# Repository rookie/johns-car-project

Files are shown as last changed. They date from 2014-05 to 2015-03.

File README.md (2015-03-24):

Overview
========

The goal of this project it to build a display for a car's instrument panel.

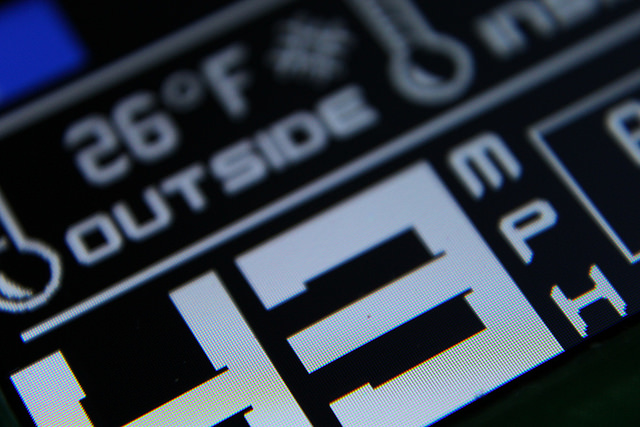
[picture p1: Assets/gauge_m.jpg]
Gauge display


Display will include
- Engine coolant temp
- External temp
- Internal temp
- Speed (from GPS)
- Time (from GPS)
- Date (from GPS)
- Button input to toggle display between Metric to Imperial
- Button input to toggle time offset for Daylight Saving

Parts List
==========

- 1x Arduino Pro Mini 328 - https://www.sparkfun.com/products/11113
- 1x Adafruit 2.2" LCD - http://www.adafruit.com/products/1480
- 1x Adafruit Ultimate GPS - http://www.adafruit.com/products/746
- 3x ACDelco / GM Ambient Temperature Sensor (10K @ 25°C) - http://www.newgmparts.com/oe-gm/15936931

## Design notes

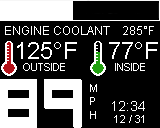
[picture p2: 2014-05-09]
Assets/gauge2.bmp

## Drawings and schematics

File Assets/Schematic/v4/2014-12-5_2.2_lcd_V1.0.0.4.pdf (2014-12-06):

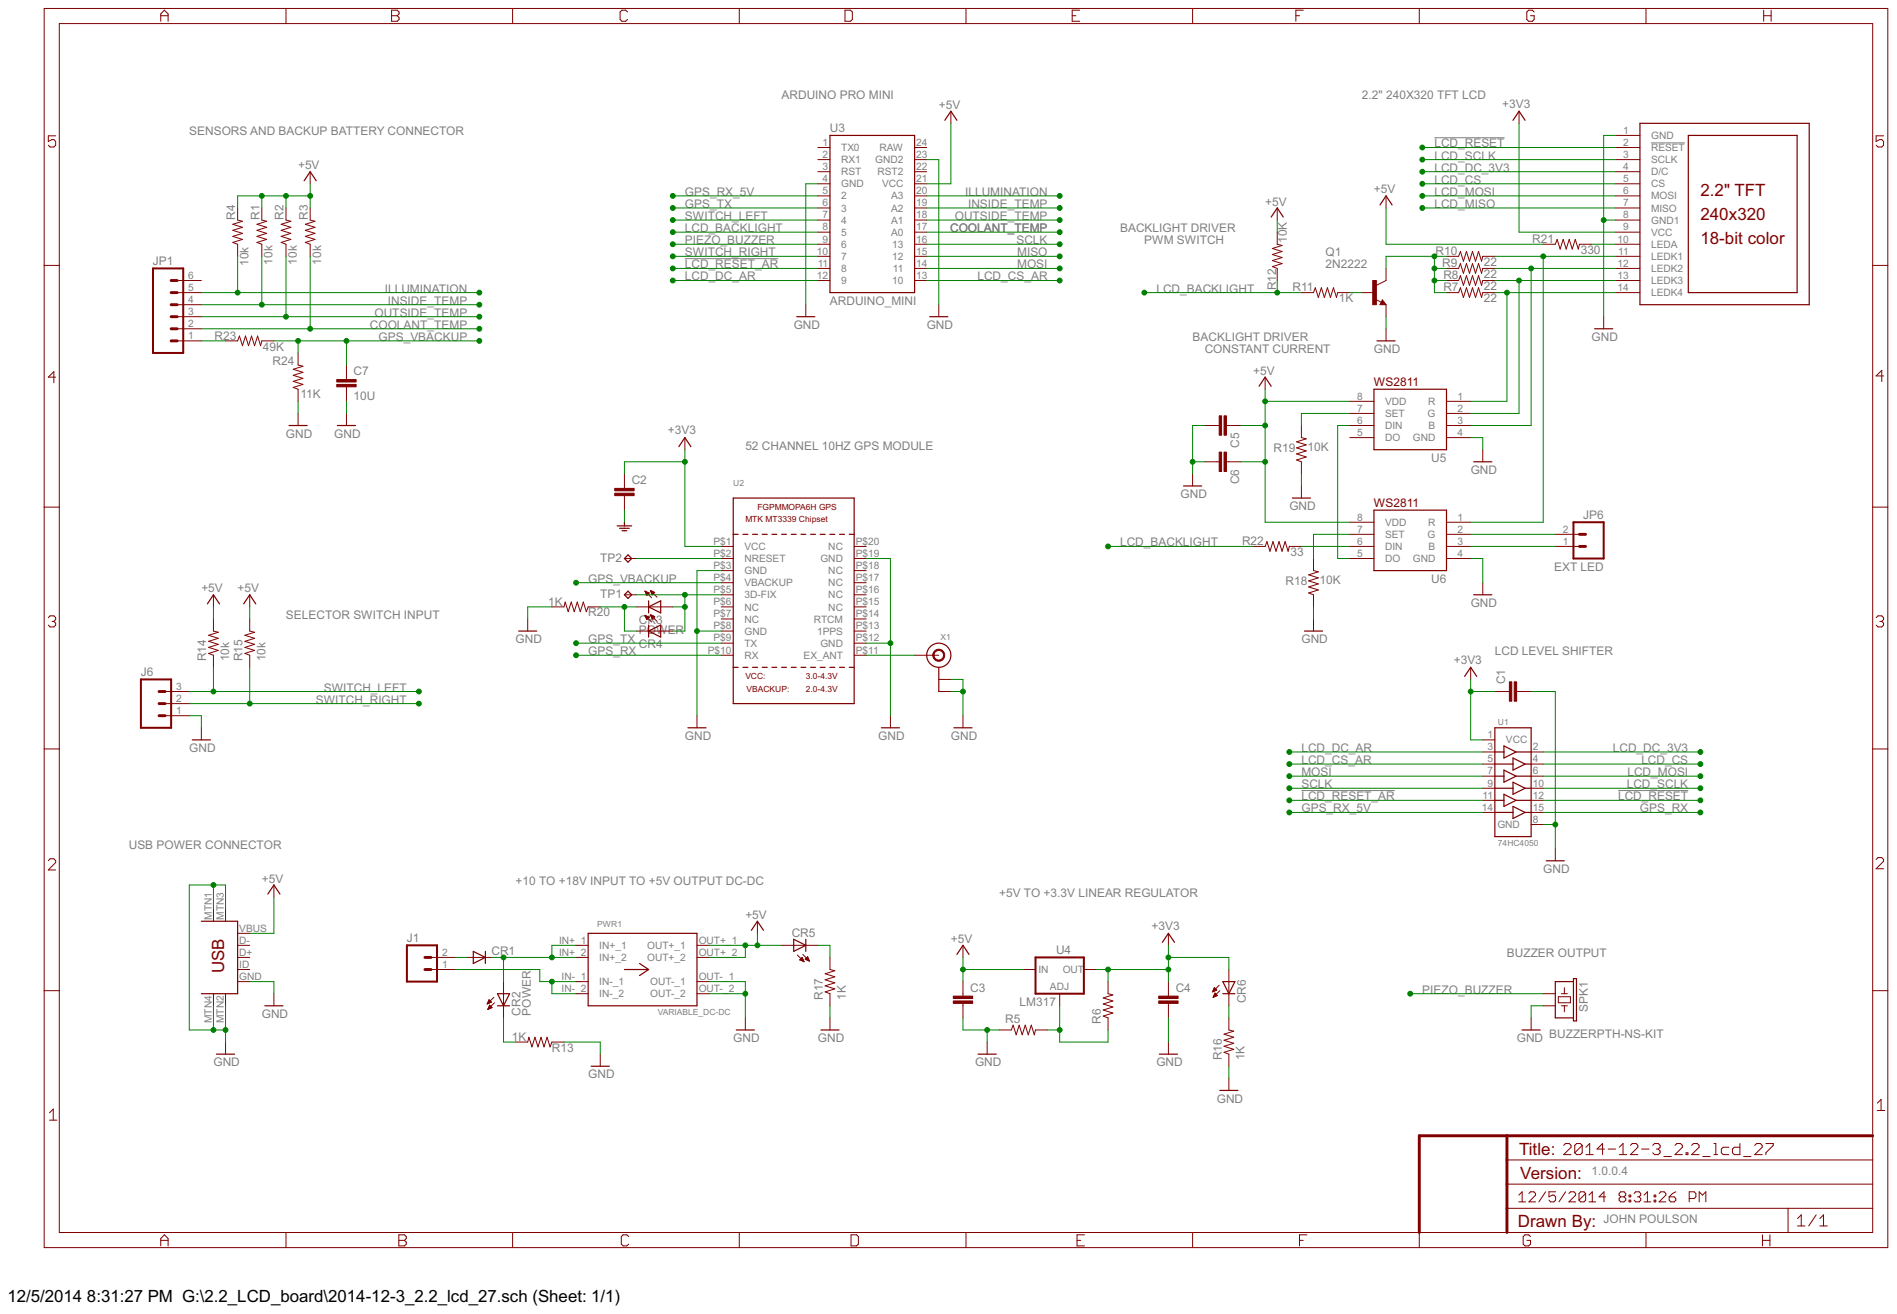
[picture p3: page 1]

SENSORS AND BACKUP BATTERY CONNECTOR

+10 TO +18V INPUT TO +5V OUTPUT DC-DC

GND BUZZERPTH-NS-KIT

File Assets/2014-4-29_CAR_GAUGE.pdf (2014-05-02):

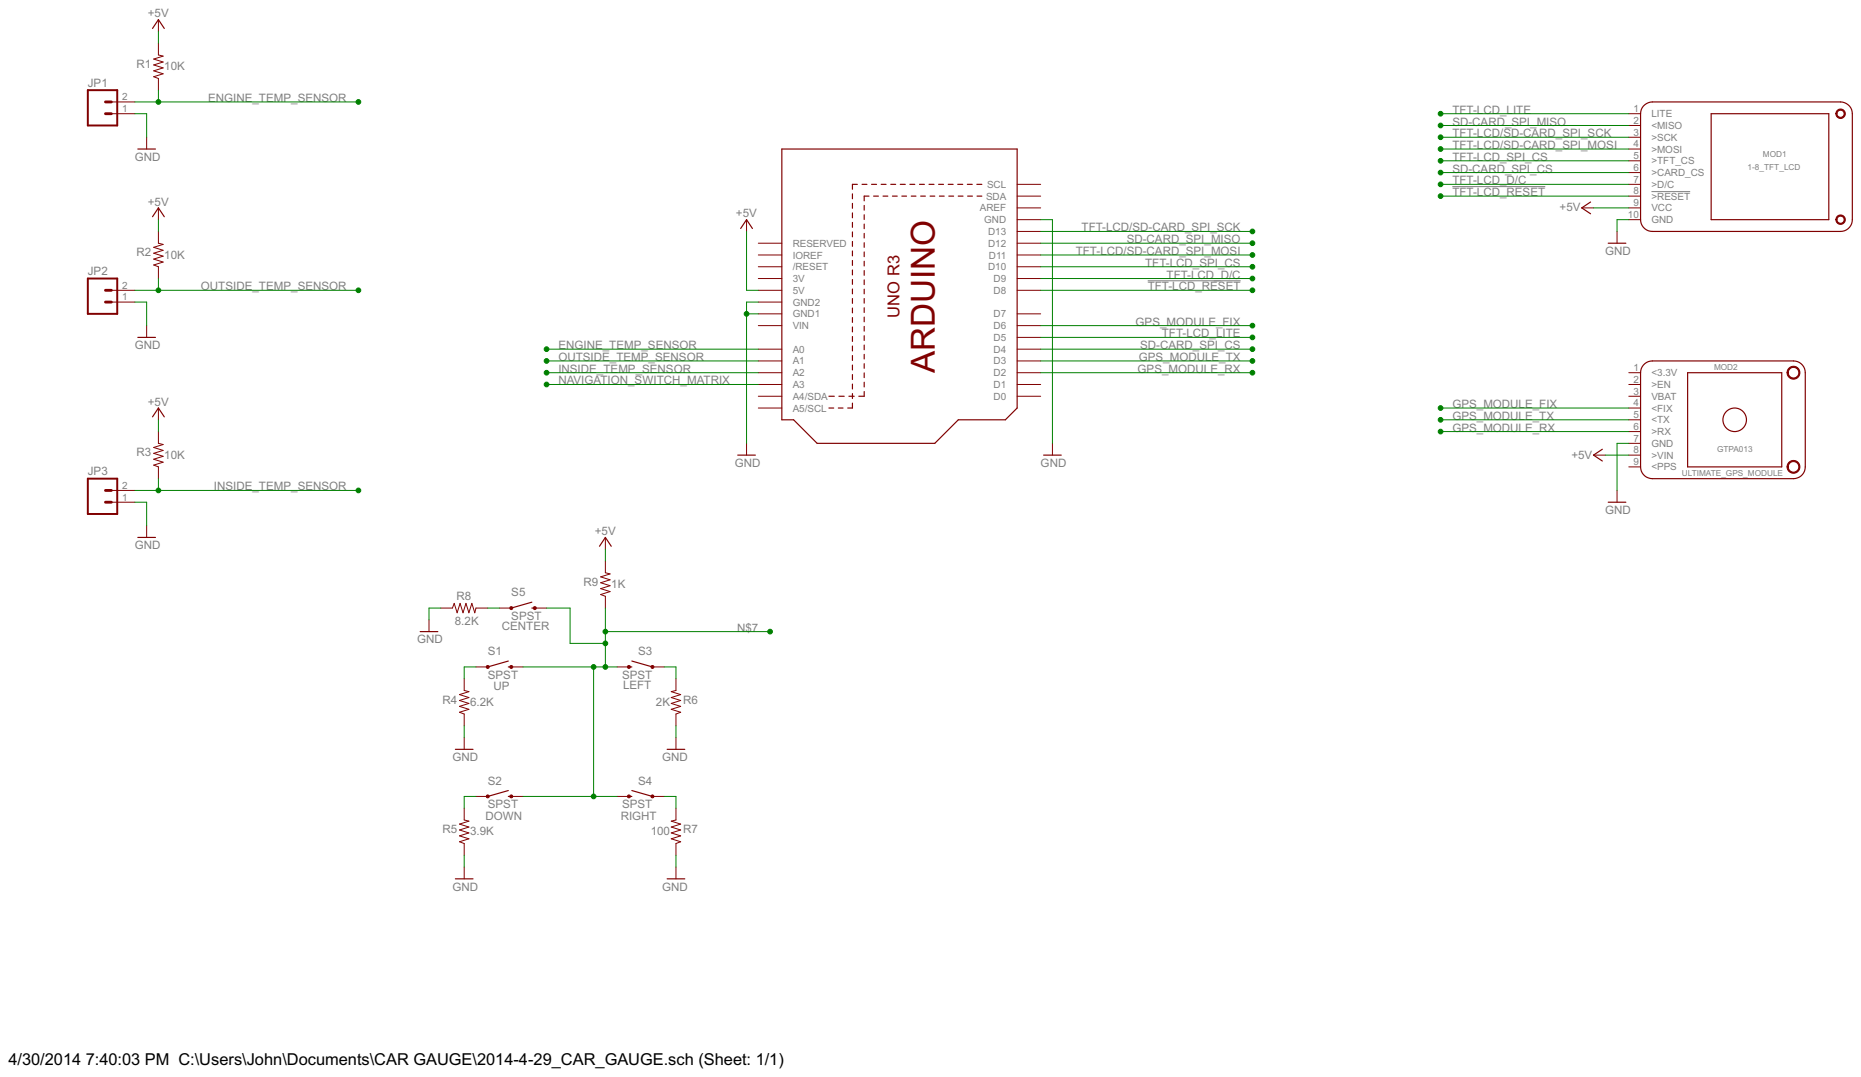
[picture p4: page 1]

4/30/2014 7:40:03 PM C:\Users\John\Documents\CAR GAUGE\2014-4-29_CAR_GAUGE.sch (Sheet: 1/1)

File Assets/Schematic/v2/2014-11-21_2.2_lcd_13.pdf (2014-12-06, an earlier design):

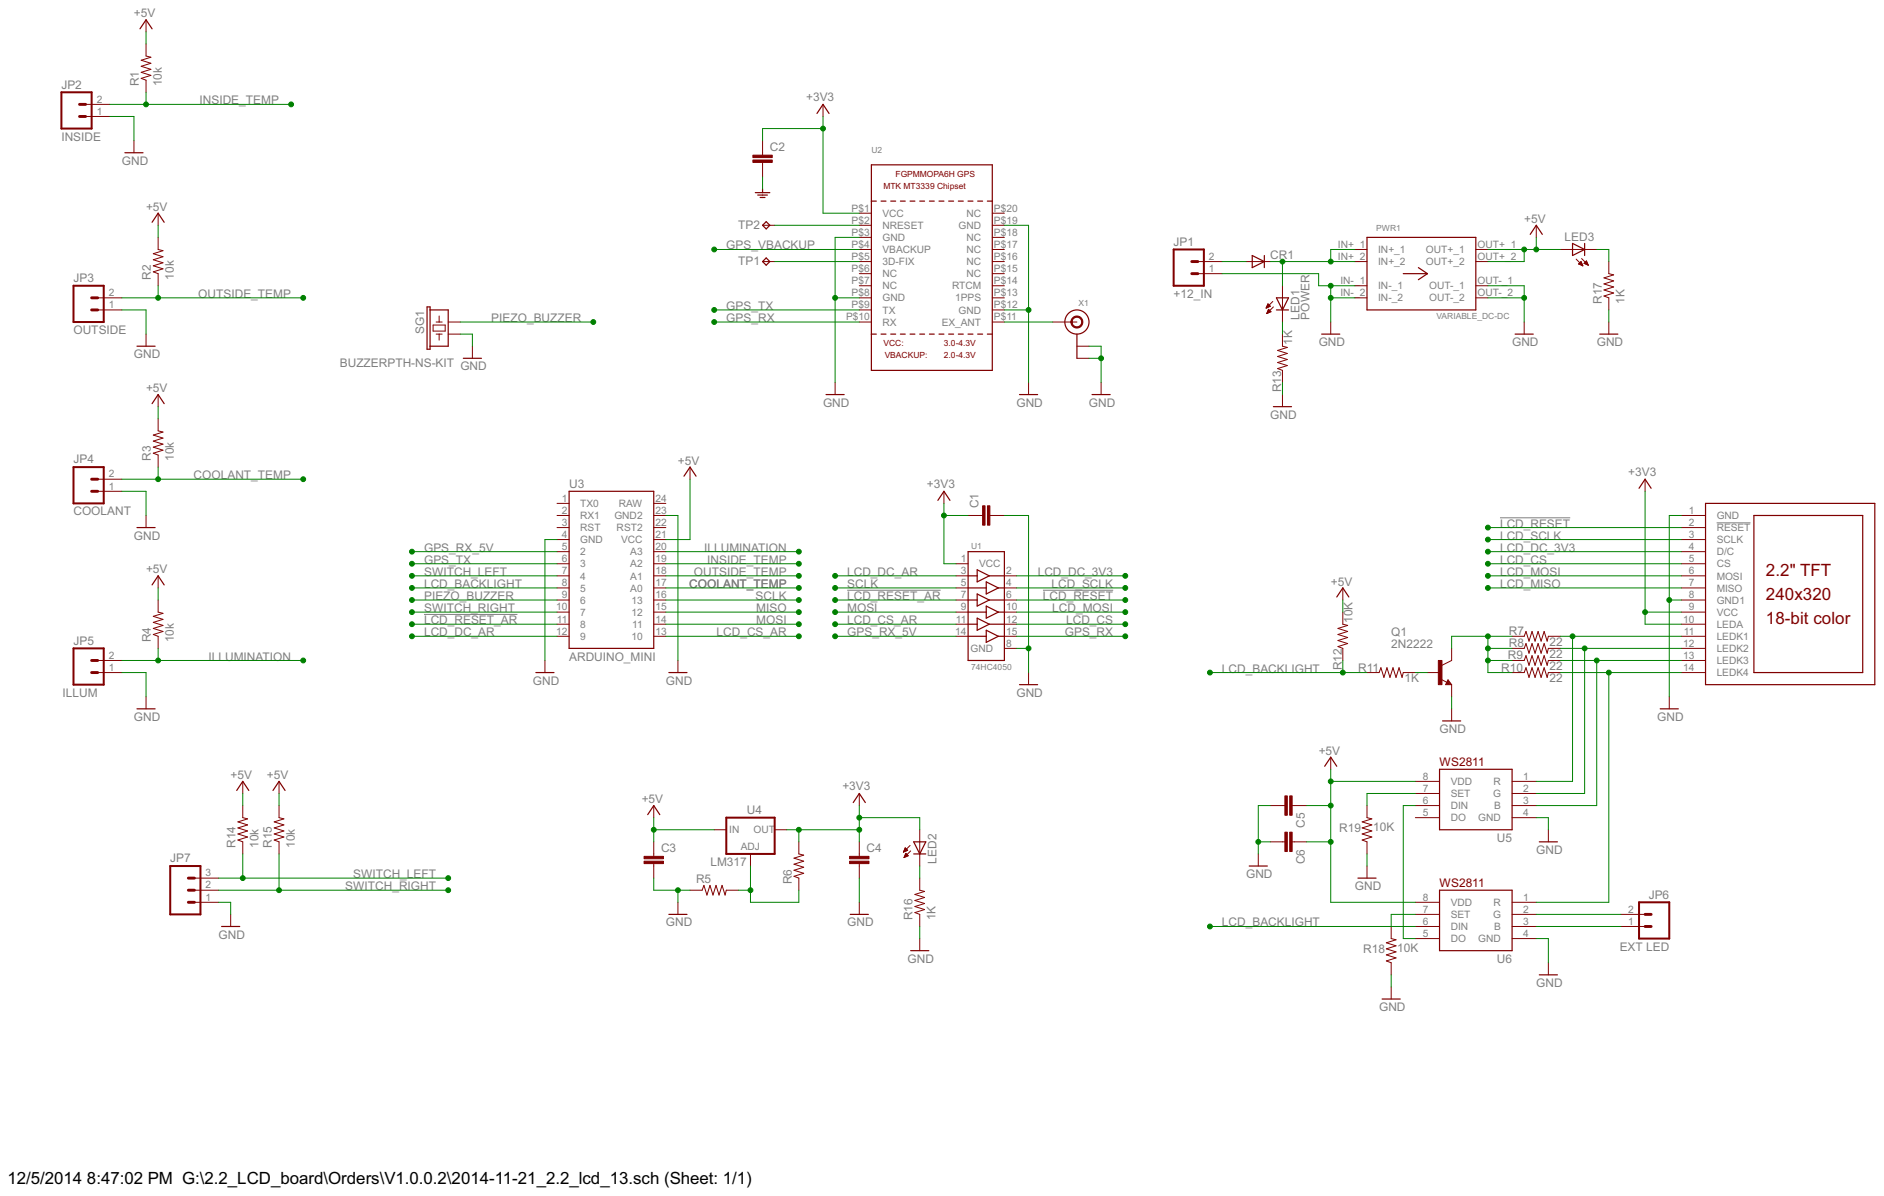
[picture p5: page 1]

BUZZERPTH-NS-KIT GND

12/5/2014 8:47:02 PM G:\2.2_LCD_board\Orders\V1.0.0.2\2014-11-21_2.2_lcd_13.sch (Sheet: 1/1)

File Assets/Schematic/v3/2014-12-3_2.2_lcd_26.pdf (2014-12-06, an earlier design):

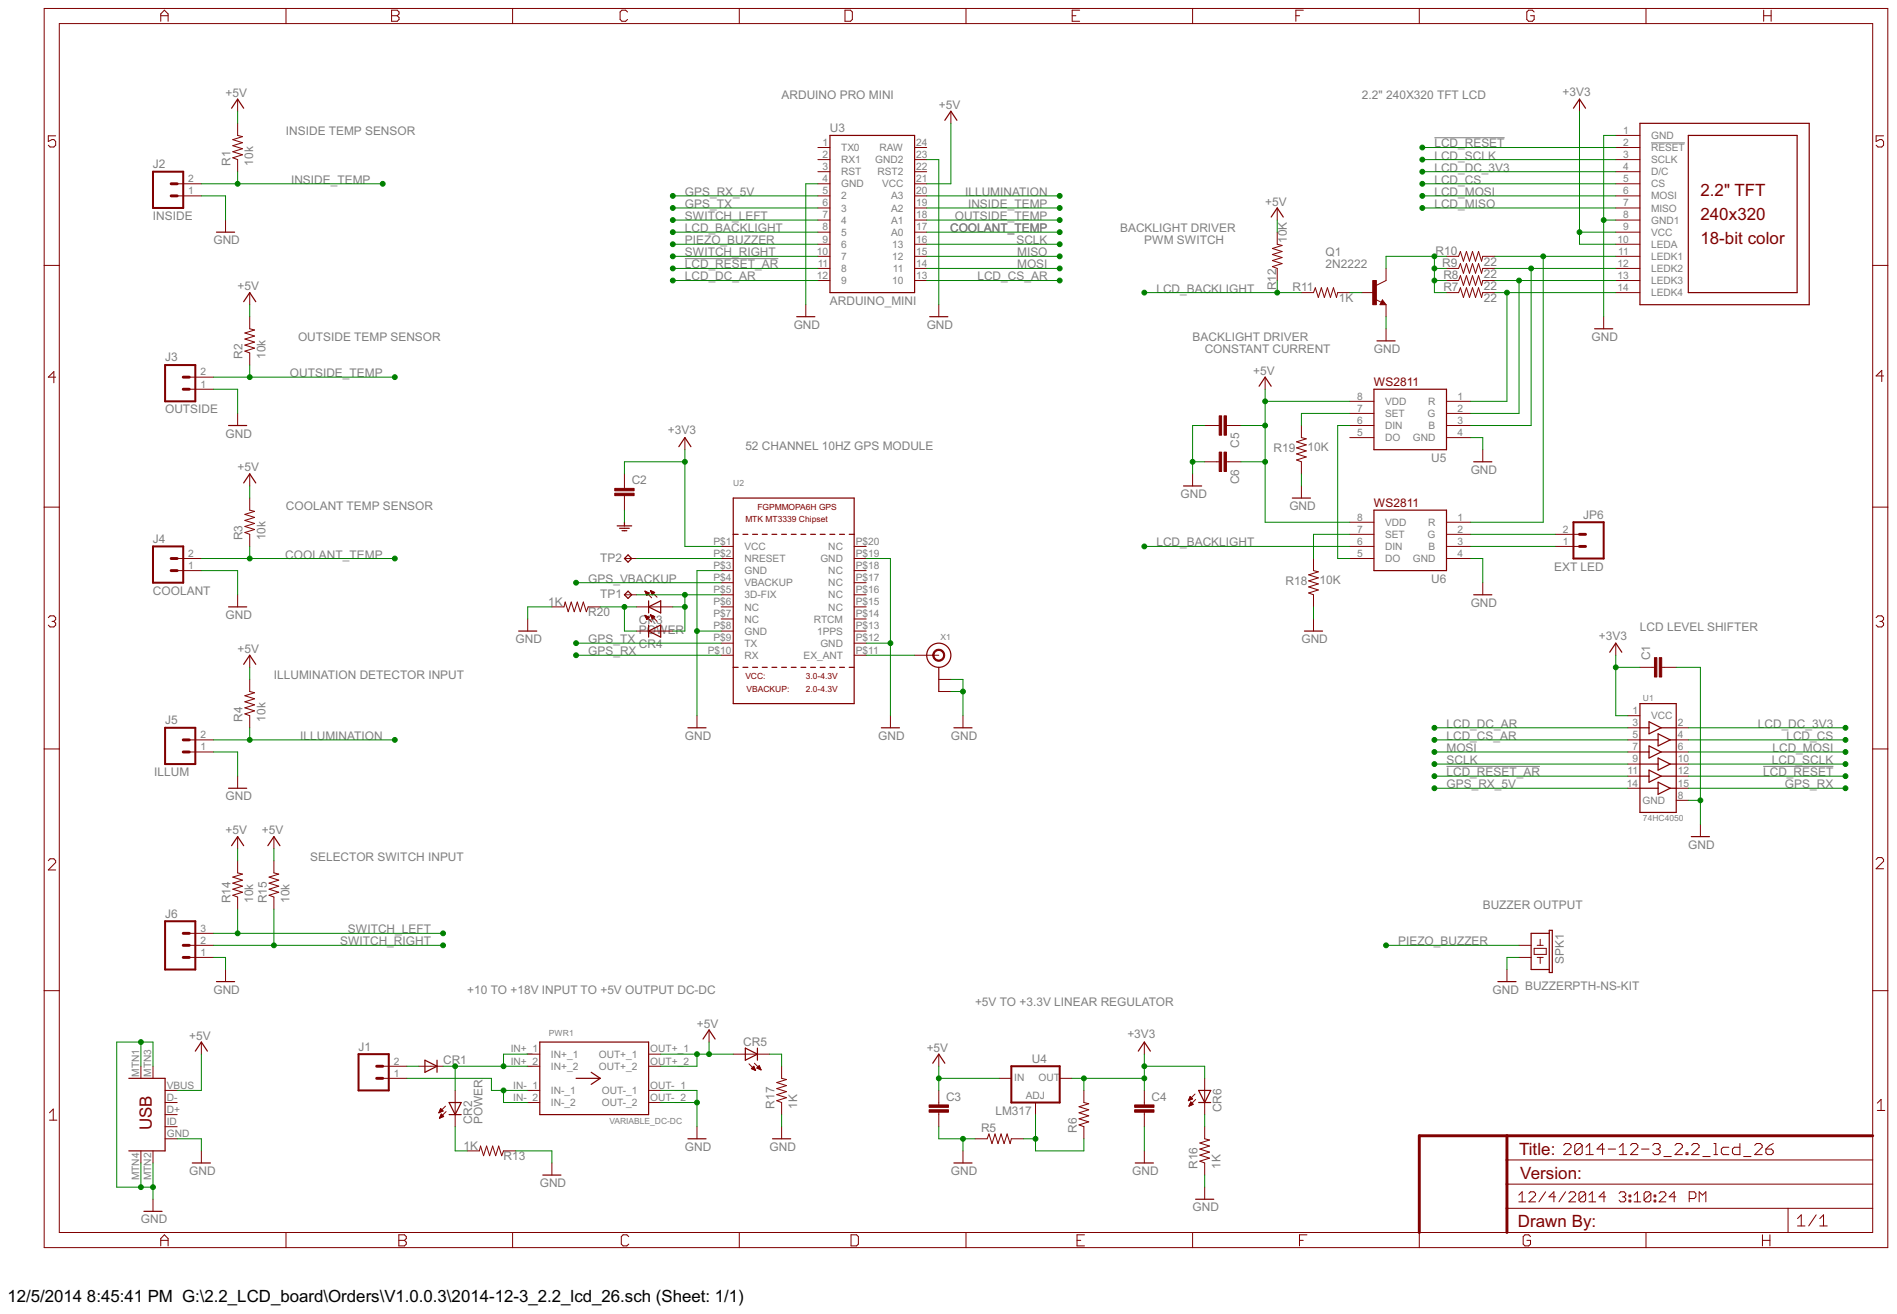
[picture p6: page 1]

+10 TO +18V INPUT TO +5V OUTPUT DC-DC

12/5/2014 8:45:41 PM G:\2.2_LCD_board\Orders\V1.0.0.3\2014-12-3_2.2_lcd_26.sch (Sheet: 1/1)

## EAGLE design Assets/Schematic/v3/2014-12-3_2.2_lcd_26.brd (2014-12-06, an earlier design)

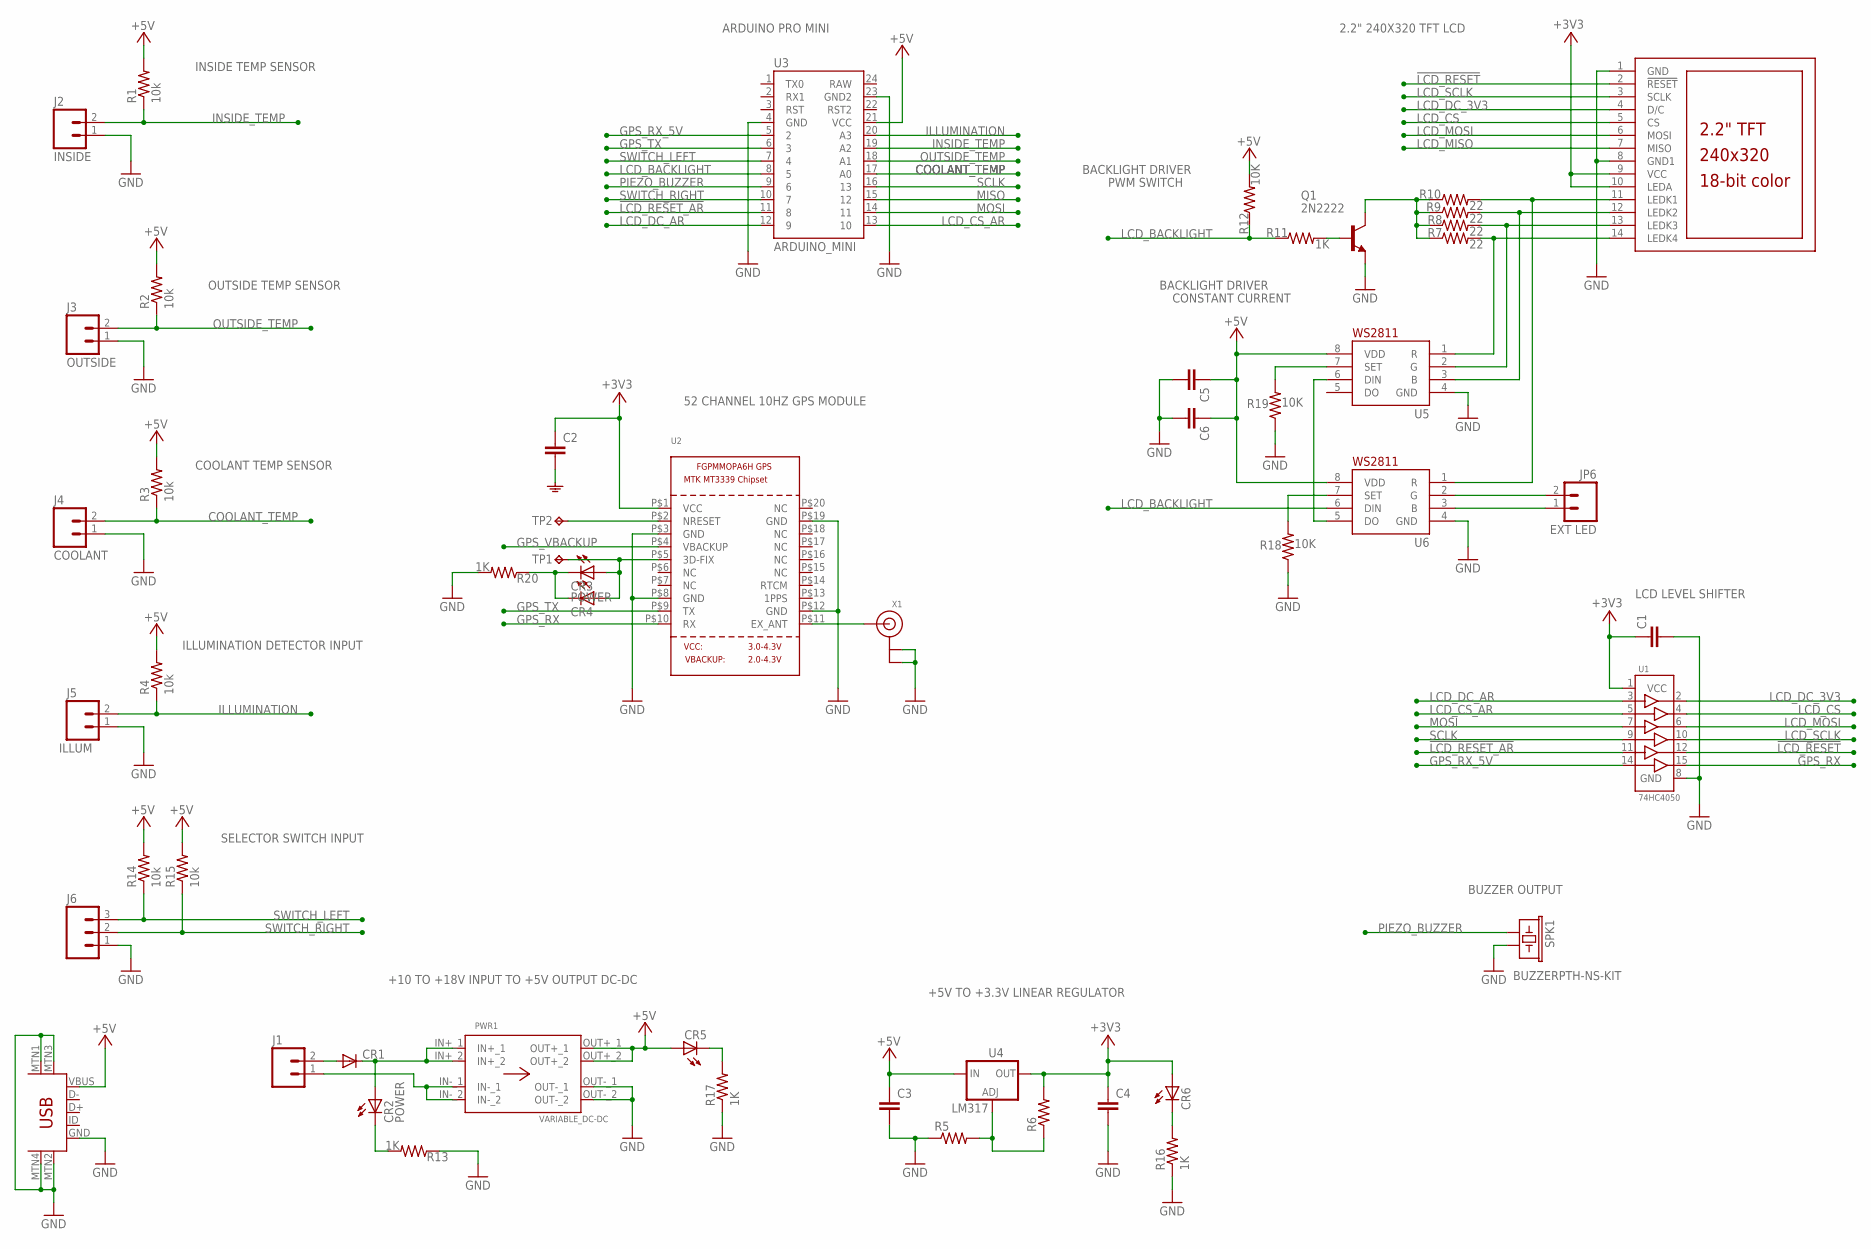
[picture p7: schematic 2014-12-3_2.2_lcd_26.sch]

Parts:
C1, C2, C3, C4, C5, C6: CAP0805; 0805
CR1: DIODESMB; SMB-DIODE
CR2, CR3: POWER; LED3MM
CR4, CR5, CR6: LED0603; LED-0603
J1: M02POLAR; MOLEX-1X2
J2: INSIDE; MOLEX-1X2
J3: OUTSIDE; MOLEX-1X2
J4: COOLANT; MOLEX-1X2
J5: ILLUM; MOLEX-1X2
J6: M03POLAR; MOLEX-1X3
JP6: EXT LED; MOLEX-1X2
PWR1: VARIABLE_DC-DC
Q1: 2N2222; TO92
R1, R2, R3, R4, R14, R15: 10k; 0805
R5, R6: RESISTOR0805-RES; 0805
R7, R8, R9, R10: 22; 0805
R11, R13, R16, R17, R20: 1K; 0805
R12, R18, R19: 10K; 0805
SPK1: BUZZERPTH-NS-KIT; BUZZER-12MM-NS-KIT
TP1, TP2: TPPAD1-13; P1-13
U1: 74HC4050; SO16
U2: GPS_FGPMMOPA6H; FGPMMOPA6H
U3: ARDUINO_MINI
U4: LM317; SOT223
U5, U6: WS2811-SOP8; SO08-SKINNYPADS
U$2: 2.2_LCD
USB: USB-MINIB-5PIN; USB-MINIB
X1: ANTENNA_U.FL; U.FL

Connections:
!LCD_RESET: U1.12, U$2.2 (!RESET)
!LCD_RESET_AR: U1.11, U3.11 (8)
+3V3: C1.1, C2.1, C4.1, CR6.A, R6.2, U1.1 (VCC), U2.P$1 (VCC), U4.2 (OUT), U$2.9 (VCC), U$2.10 (LEDA)
+5V: C3.1, C5.1, C6.1, CR5.A, PWR1.OUT+_1, PWR1.OUT+_2, R1.2, R2.2, R3.2, R4.2, R12.2, R14.2, R15.2, U3.21 (VCC), U4.3 (IN), U5.8 (VDD), U6.8 (VDD), USB.VBUS
COOLANT_TEMP: J4.2, R3.1, U3.17 (A0)
GND: C1.2, C3.2, C4.2, C5.2, C6.2, J2.1, J3.1, J4.1, J5.1, J6.1, PWR1.OUT-_1, PWR1.OUT-_2, Q1.1 (E), R5.1, R13.1, R16.1, R17.1, R18.1, R19.1, R20.2, SPK1.- (2), U1.8 (GND), U2.P$3 (GND), U2.P$8 (GND), U2.P$12 (GND), U2.P$19 (GND), U3.4 (GND), U3.23 (GND2), U5.4 (GND), U6.4 (GND), U$2.1 (GND), U$2.8 (GND1), USB.GND, USB.MTN1 (MTN2), USB.MTN2 (MTN3), USB.MTN3 (MTN1), USB.MTN4, X1.1 (GND), X1.2 (GND)
GPS_RX: U1.15, U2.P$10 (RX)
GPS_RX_5V: U1.14, U3.5 (2)
GPS_TX: U2.P$9 (TX), U3.6 (3)
GPS_VBACKUP: U2.P$4 (VBACKUP)
ILLUMINATION: J5.2, R4.1, U3.20 (A3)
INSIDE_TEMP: J2.2, R1.1, U3.19 (A2)
LCD_BACKLIGHT: R11.1, R12.1, U3.8 (5), U6.6 (DIN)
LCD_CS: U1.4, U$2.5 (CS)
LCD_CS_AR: U1.5, U3.13 (10)
LCD_DC_3V3: U1.2, U$2.4 (D/C)
LCD_DC_AR: U1.3, U3.12 (9)
LCD_MISO: U$2.7 (MISO)
LCD_MOSI: U1.6, U$2.6 (MOSI)
LCD_SCLK: U1.10, U$2.3 (SCLK)
MISO: U3.15 (12)
MOSI: U1.7, U3.14 (11)
unnamed: TP2.TP, U2.P$2 (NRESET)
unnamed: U2.P$11 (EX_ANT), X1.3 (SIGNAL)
unnamed: R7.2, U5.1 (R), U$2.14 (LEDK4)
unnamed: R8.2, U5.2 (G), U$2.13 (LEDK3)
unnamed: R9.2, U5.3 (B), U$2.12 (LEDK2)
unnamed: R5.2, R6.1, U4.1 (ADJ)
unnamed: R10.2, U6.1 (R), U$2.11 (LEDK1)
unnamed: Q1.3 (C), R7.1, R8.1, R9.1, R10.1
unnamed: Q1.2 (B), R11.2
unnamed: CR1.A, J1.2
unnamed: CR1.C, CR2.A, PWR1.IN+_1, PWR1.IN+_2
unnamed: J1.1, PWR1.IN-_1, PWR1.IN-_2
unnamed: JP6.2, U6.2 (G)
unnamed: CR3.K (C), CR4.C, R20.1
unnamed: CR2.K (C), R13.2
unnamed: CR3.A, CR4.A, TP1.TP, U2.P$5 (3D-FIX)
unnamed: CR6.C, R16.2
unnamed: CR5.C, R17.2
unnamed: U5.6 (DIN), U6.5 (DO)
unnamed: R18.2, U6.7 (SET)
unnamed: JP6.1, U6.3 (B)
unnamed: R19.2, U5.7 (SET)
OUTSIDE_TEMP: J3.2, R2.1, U3.18 (A1)
P$1: C2.2
PIEZO_BUZZER: SPK1.+ (1), U3.9 (6)
SCLK: U1.9, U3.16 (13)
SWITCH_LEFT: J6.3, R14.1, U3.7 (4)
SWITCH_RIGHT: J6.2, R15.1, U3.10 (7)

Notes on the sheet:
ARDUINO PRO MINI
2.2" 240X320 TFT LCD
BACKLIGHT DRIVER
CONSTANT CURRENT
PWM SWITCH
LCD LEVEL SHIFTER
BUZZER OUTPUT
+5V TO +3.3V LINEAR REGULATOR
+10 TO +18V INPUT TO +5V OUTPUT DC-DC
SELECTOR SWITCH INPUT
ILLUMINATION DETECTOR INPUT
COOLANT TEMP SENSOR
OUTSIDE TEMP SENSOR
INSIDE TEMP SENSOR
52 CHANNEL 10HZ GPS MODULE

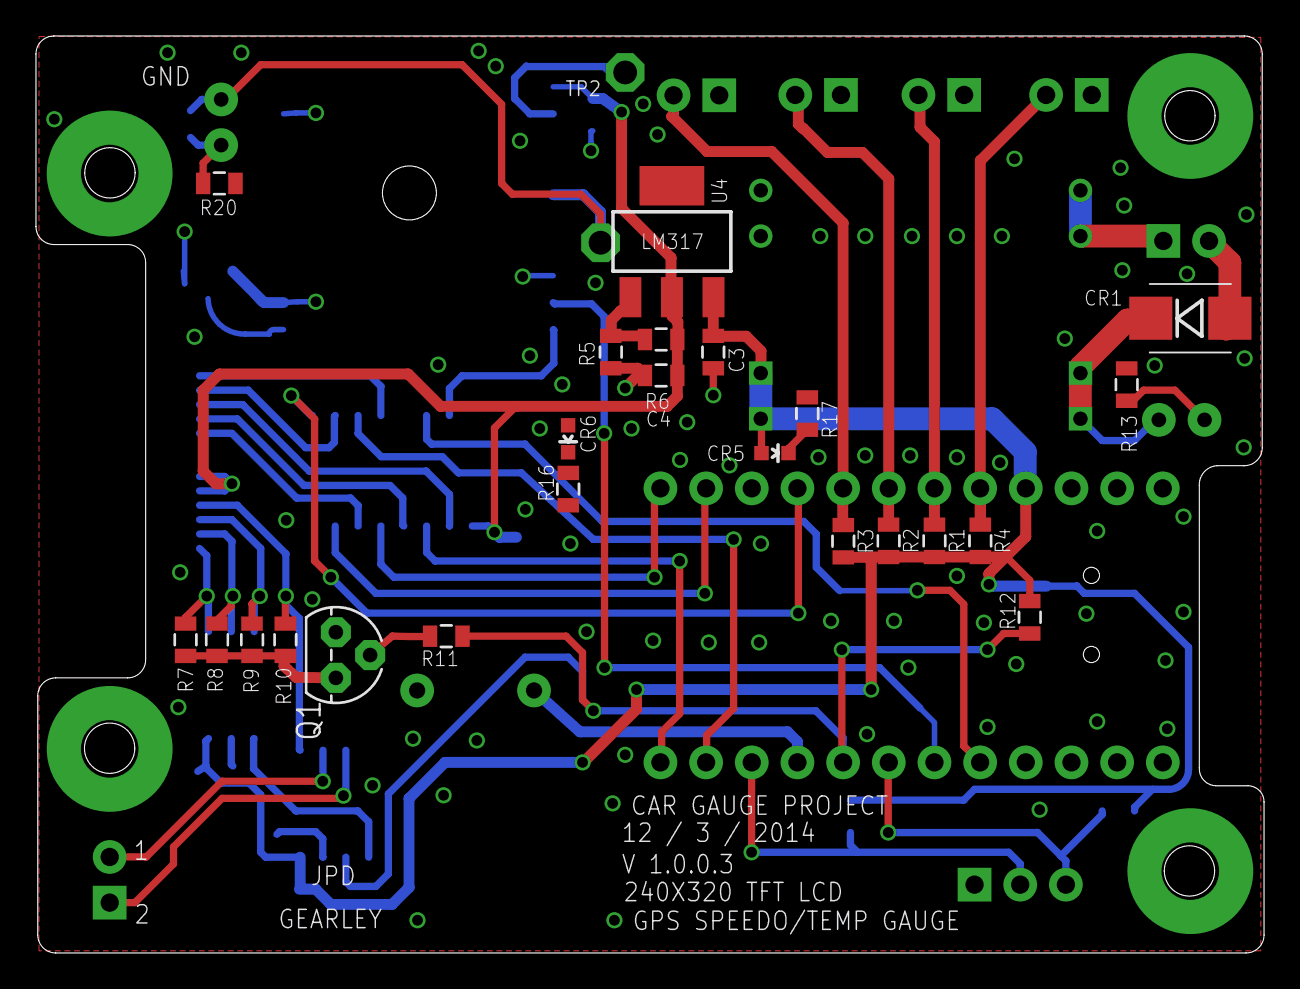
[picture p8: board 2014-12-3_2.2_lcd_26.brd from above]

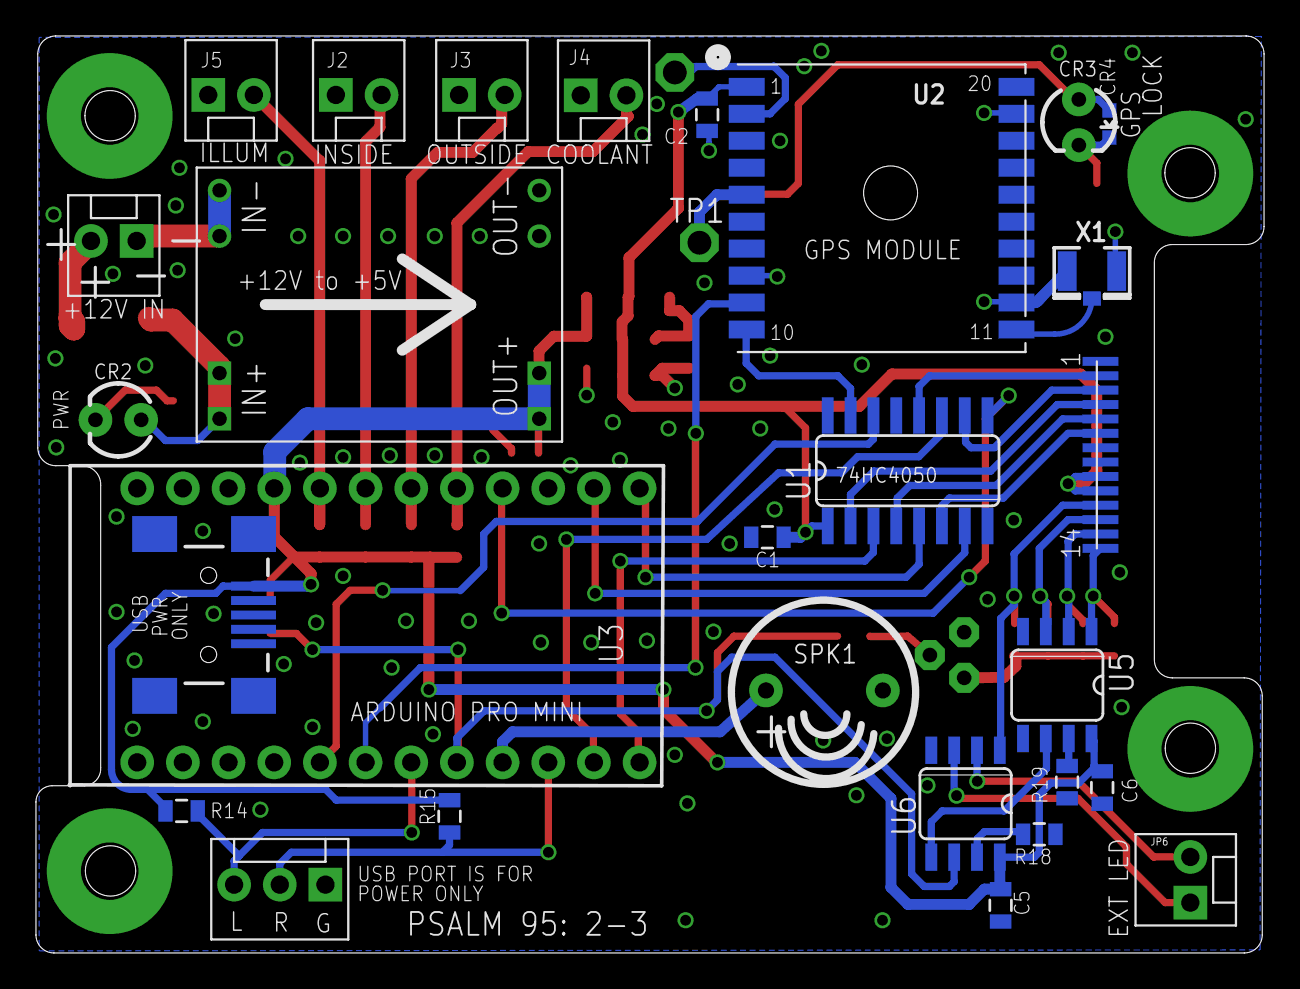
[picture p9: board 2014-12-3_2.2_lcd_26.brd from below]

Board: 2 copper layers, 68.3 x 51.0 mm, 53 parts (29 on the bottom side), 46 nets.

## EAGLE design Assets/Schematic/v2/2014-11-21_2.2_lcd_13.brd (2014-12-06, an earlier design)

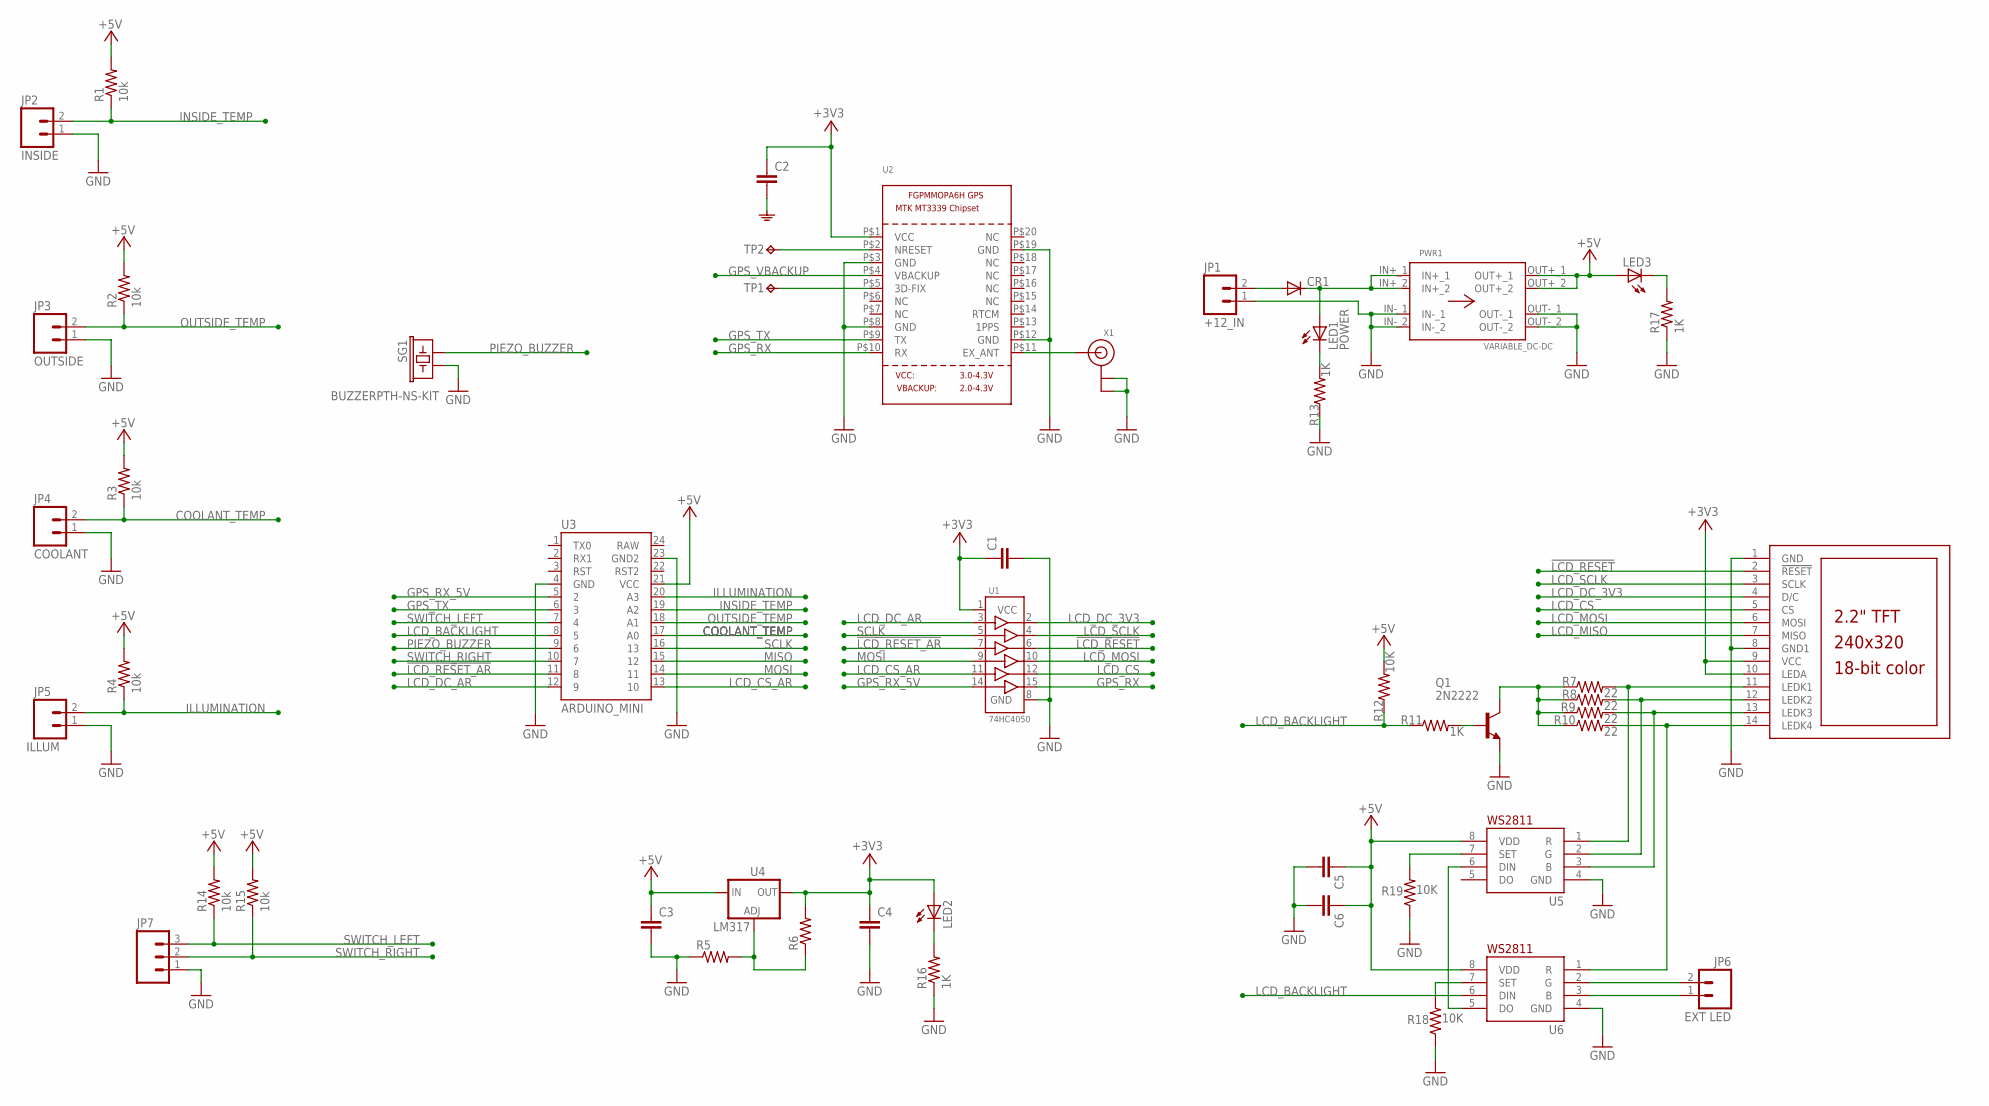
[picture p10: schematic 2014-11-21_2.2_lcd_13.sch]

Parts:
C1, C2, C3, C4: CAP0805; 0805
C5, C6: CAP0603-CAP; 0603-CAP
CR1: DIODESMA-ALT; SMA-DIODE_ALT
JP1: +12_IN; JST-2-PTH-VERT
JP2: INSIDE; JST-2-PTH-VERT
JP3: OUTSIDE; JST-2-PTH-VERT
JP4: COOLANT; JST-2-PTH-VERT
JP5: ILLUM; JST-2-PTH-VERT
JP6: EXT LED; JST-2-PTH-VERT
JP7: M03POLAR; MOLEX-1X3
LED1: POWER; LED3MM
LED2, LED3: LED0603; LED-0603
PWR1: VARIABLE_DC-DC
Q1: 2N2222; TO92
R1, R2, R3, R4, R14, R15: 10k; 0805
R5, R6: RESISTOR0805-RES; 0805
R7, R8, R9, R10: 22; 0805
R11, R13, R16, R17: 1K; 0805
R12, R18, R19: 10K; 0805
SG1: BUZZERPTH-NS-KIT; BUZZER-12MM-NS-KIT
TP1, TP2: TPPAD1-13; P1-13
U1: 74HC4050; SO16
U2: GPS_FGPMMOPA6H; FGPMMOPA6H
U3: ARDUINO_MINI
U4: LM317; SOT223
U5, U6: WS2811-SOP8; SO08-SKINNYPADS
U$1: 2.2_LCD
X1: ANTENNA_U.FL; U.FL

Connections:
!LCD_RESET: U1.6, U$1.2 (!RESET)
!LCD_RESET_AR: U1.7, U3.11 (8)
+3V3: C1.1, C2.1, C4.1, LED2.A, R6.2, U1.1 (VCC), U2.P$1 (VCC), U4.2 (OUT), U$1.9 (VCC), U$1.10 (LEDA)
+5V: C3.1, C5.1, C6.1, LED3.A, PWR1.OUT+_1, PWR1.OUT+_2, R1.2, R2.2, R3.2, R4.2, R12.2, R14.2, R15.2, U3.21 (VCC), U4.3 (IN), U5.8 (VDD), U6.8 (VDD)
COOLANT_TEMP: JP4.2, R3.1, U3.17 (A0)
GND: C1.2, C3.2, C4.2, C5.2, C6.2, JP1.1, JP2.1, JP3.1, JP4.1, JP5.1, JP7.1, PWR1.IN-_1, PWR1.IN-_2, PWR1.OUT-_1, PWR1.OUT-_2, Q1.1 (E), R5.1, R13.1, R16.1, R17.1, R18.1, R19.1, SG1.- (2), U1.8 (GND), U2.P$3 (GND), U2.P$8 (GND), U2.P$12 (GND), U2.P$19 (GND), U3.4 (GND), U3.23 (GND2), U5.4 (GND), U6.4 (GND), U$1.1 (GND), U$1.8 (GND1), X1.1 (GND), X1.2 (GND)
GPS_RX: U1.15, U2.P$10 (RX)
GPS_RX_5V: U1.14, U3.5 (2)
GPS_TX: U2.P$9 (TX), U3.6 (3)
GPS_VBACKUP: U2.P$4 (VBACKUP)
ILLUMINATION: JP5.2, R4.1, U3.20 (A3)
INSIDE_TEMP: JP2.2, R1.1, U3.19 (A2)
LCD_BACKLIGHT: R11.1, R12.1, U3.8 (5), U6.6 (DIN)
LCD_CS: U1.12, U$1.5 (CS)
LCD_CS_AR: U1.11, U3.13 (10)
LCD_DC_3V3: U1.2, U$1.4 (D/C)
LCD_DC_AR: U1.3, U3.12 (9)
LCD_MISO: U$1.7 (MISO)
LCD_MOSI: U1.10, U$1.6 (MOSI)
LCD_SCLK: U1.4, U$1.3 (SCLK)
MISO: U3.15 (12)
MOSI: U1.9, U3.14 (11)
unnamed: TP2.TP, U2.P$2 (NRESET)
unnamed: U2.P$11 (EX_ANT), X1.3 (SIGNAL)
unnamed: R7.2, U5.1 (R), U$1.11 (LEDK1)
unnamed: R8.2, U5.2 (G), U$1.12 (LEDK2)
unnamed: R9.2, U5.3 (B), U$1.13 (LEDK3)
unnamed: R5.2, R6.1, U4.1 (ADJ)
unnamed: R10.2, U6.1 (R), U$1.14 (LEDK4)
unnamed: Q1.3 (C), R7.1, R8.1, R9.1, R10.1
unnamed: Q1.2 (B), R11.2
unnamed: CR1.A, JP1.2
unnamed: CR1.C, LED1.A, PWR1.IN+_1, PWR1.IN+_2
unnamed: JP6.2, U6.2 (G)
unnamed: LED1.K (C), R13.2
unnamed: TP1.TP, U2.P$5 (3D-FIX)
unnamed: LED2.C, R16.2
unnamed: LED3.C, R17.2
unnamed: U5.6 (DIN), U6.5 (DO)
unnamed: R18.2, U6.7 (SET)
unnamed: JP6.1, U6.3 (B)
unnamed: R19.2, U5.7 (SET)
OUTSIDE_TEMP: JP3.2, R2.1, U3.18 (A1)
P$1: C2.2
PIEZO_BUZZER: SG1.+ (1), U3.9 (6)
SCLK: U1.5, U3.16 (13)
SWITCH_LEFT: JP7.3, R14.1, U3.7 (4)
SWITCH_RIGHT: JP7.2, R15.1, U3.10 (7)

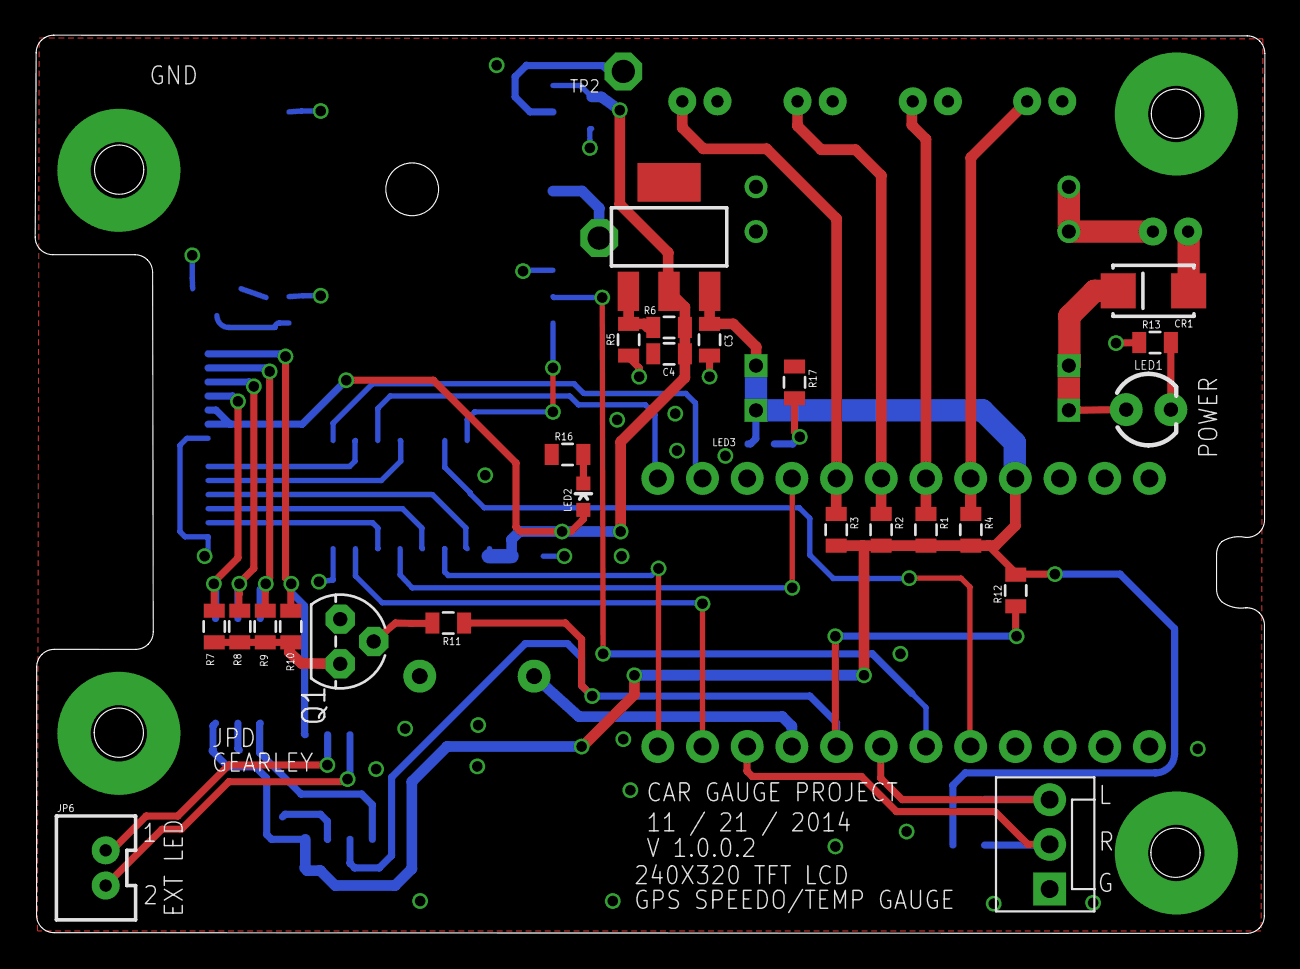
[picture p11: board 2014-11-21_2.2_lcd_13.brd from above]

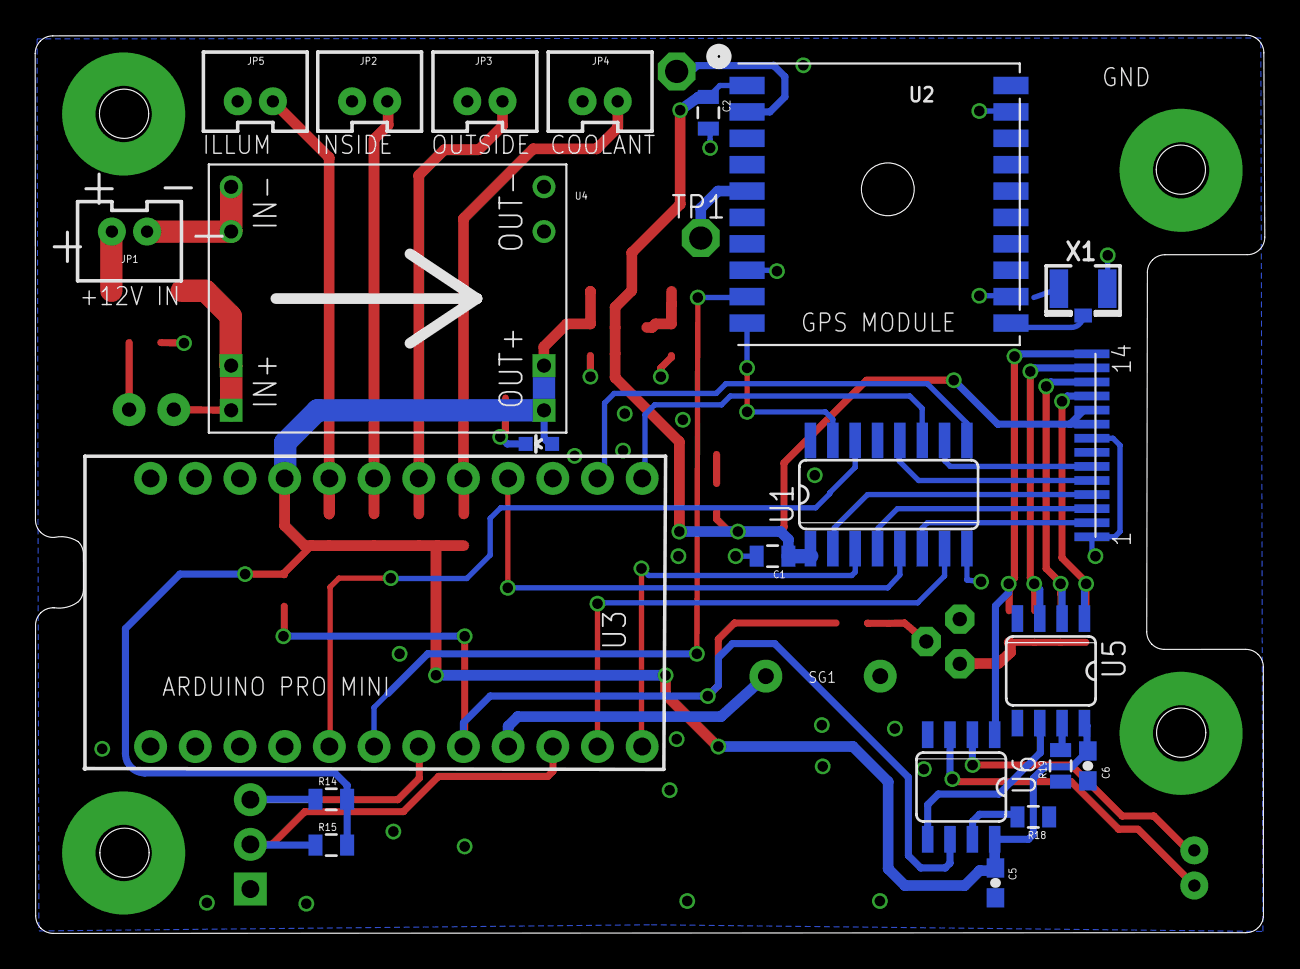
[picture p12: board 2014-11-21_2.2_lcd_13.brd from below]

Board: 2 copper layers, 69.9 x 51.0 mm, 49 parts (24 on the bottom side), 44 nets.

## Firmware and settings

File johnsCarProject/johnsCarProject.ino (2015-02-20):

/***************************************************
  This is an example sketch for the Adafruit 1.8" SPI display.
  This library works with the Adafruit 1.8" TFT Breakout w/SD card
  ----> http://www.adafruit.com/products/358
  as well as Adafruit raw 1.8" TFT display
  ----> http://www.adafruit.com/products/618
 
  Check out the links above for our tutoriajohns-car-projectls and wiring diagrams
  These displays use SPI to communicate, 4 or 5 pins are required to
  interface (RST is optional)
  Adafruit invests time and resources providing this open source code,
  please support Adafruit and open-source hardware by purchasing
  products from Adafruit!

  Written by Limor Fried/Ladyada for Adafruit Industries.
  MIT license, all text above must be included in any redistribution
 ****************************************************/

//TODO: add string term \0 to UIvalues, somebody will print them someday

int debug_demo_mode = 0;
int debug_fast_baud = 1;
int debug_fast_update = 1;
int debug_show_gps_fix = 1;

#define tempCoolantPin A0
#define tempOutsidePin A1
#define tempInsidePin  A2

// For the breakout, you can use any (2 or) 3 pins
//#define sclk 13
//#define mosi 11
#define cs   10
#define dc   9
#define rst  8  // you can also connect this to the Arduino reset

#define light 5
//Use these pins for the shield!
//#define cs   10
//#define dc   8
//#define rst  0  // you can also connect this to the Arduino reset

#define gpsPin 3

#include <Time.h>

//#include <Adafruit_GFX.h>    // Core graphics library
//#include <Adafruit_ILI9340.h> // 2.2inch
//Adafruit_ILI9340 tft = Adafruit_ILI9340(cs, dc, rst);

#include <PDQ_GFX.h>				// PDQ: Core graphics library
#include "PDQ_ILI9340_config.h"			// PDQ: ST7735 pins and other setup for this sketch
#include <PDQ_ILI9340.h>			// PDQ: Hardware-specific driver library
PDQ_ILI9340 tft;				// PDQ: create LCD object (using pins in "PDQ_ST7735_config.h")


#include <SPI.h>
//GPS
#include <Adafruit_GPS.h>
#include <SoftwareSerial.h>

#define COLOR_WHITE ILI9340_WHITE
#define COLOR_BLACK ILI9340_BLACK
#define COLOR_RED   ILI9340_RED  
#define COLOR_GREEN   ILI9340_GREEN  
#define COLOR_YELLOW ILI9340_YELLOW
#define COLOR_BLUE ILI9340_BLUE

//GPS
// If using software serial, keep these lines enabled
// (you can change the pin numbers to match your wiring):
SoftwareSerial mySerial(3, 2); //2 is tx 3 is overridden HIGH by gpsPin

#define DSerial mySerial
//#define DSerial Serial


//Serial = NULL;

//Adafruit_GPS GPS(&mySerial);
// If using hardware serial (e.g. Arduino Mega), comment
// out the above six lines and enable this line instead:
Adafruit_GPS GPS(&Serial);


// Set GPSECHO to 'false' to turn off echoing the GPS data to the Serial console
// Set to 'true' if you want to debug and listen to the raw GPS sentences. 
#define GPSECHO  false

// this keeps track of whether we're using the interrupt
// off by default!
boolean usingInterrupt = false;
void useInterrupt(boolean); // Func prototype keeps Arduino 0023 happy


uint16_t fgColor = COLOR_WHITE;
uint16_t bgColor = COLOR_BLACK;
typedef enum {IMPERIAL, METRIC, NONE} displayMode_t;
displayMode_t displayMode = IMPERIAL;
int offsetDST = 0;

struct values {
   uint16_t coolantValue;
   uint16_t outsideValue;
   uint16_t insideValue;
   
   uint8_t fix;
   //These might all come over as strings
   float speedKnots; //Knots
   int speedMPH; //MPH
   int speedKPH; //KPH
   uint8_t hour;
   uint8_t min;
   uint8_t day;
   uint8_t month;
};
struct displayValues {
   char coolantTemp[4];
   char outsideTemp[4];
   char insideTemp[4];
   int16_t coolantTempValue;
   int16_t outsideTempValue;
   int16_t insideTempValue;
   char speed[4];
   char time[6];  //12:02
   char date[6];  //12/13 or 12/12
};

struct values sensorValues;
struct values sensorsUpdated; //0 for not changed, 1 for changed
struct displayValues displayF;
struct displayValues displayC;

void setup(void) {
  
  
//14400
//19200
//28800
//38400
  DSerial.begin(57600);
  DSerial.println("setup");

  setupLCD();

  tft.setRotation(3);
  //fgColor = tft.Color565(255, 165, 0);
  //fgColor = tft.Color565(255, 127, 0);
  //DSerial.print("fgColor: 0x");
  //DSerial.println(fgColor, HEX);
  
  tft.setTextColor(fgColor, bgColor);
  

  //Mode changing
  int toggleLeft_GST = digitalRead(4);
  int toggleRight_MPH = digitalRead(7);
  if(toggleLeft_GST == LOW)
  {
    DSerial.println("Set GST Offset");
    toggleDSTOffset();
  } else 
  
  if (toggleRight_MPH == LOW)
  { 
    DSerial.println("Toggle MPH/KPH");
    toggleMPHMode();
  }
  
  
  if (getDSTOffset() == 0) {
    offsetDST = 0;
  } else {
    offsetDST = 1;
  }
  
  if (getMPHMode() == 0 || debug_demo_mode) {
    displayMode = IMPERIAL;
  } else {
    displayMode = METRIC;
  }
  
  setupGPS();

  //DEBUG
  //drawDebugUI();
  drawInitialUI();
  DSerial.println("setup done");
}

#ifndef PMTK_API_SET_FIX_CTL_1HZ
#define PMTK_API_SET_FIX_CTL_1HZ  "$PMTK300,1000,0,0,0,0*1C"
#define PMTK_API_SET_FIX_CTL_5HZ  "$PMTK300,200,0,0,0,0*2F"
#endif

//http://www.hhhh.org/wiml/proj/nmeaxor.html
#define PMTK_SET_BAUD_14400  "$PMTK251,14400*29"
#define PMTK_SET_BAUD_19200  "$PMTK251,19200*22"
//#define PMTK_SET_BAUD_28800  "$PMTK251,28800*2A"
#define PMTK_SET_BAUD_38400  "$PMTK251,38400*27"


void setupGPS()
{
  DSerial.println("setupGPS()");
  
  //Enable GPS
  pinMode(gpsPin, OUTPUT);
  digitalWrite(gpsPin, HIGH);
  delay(1000);

  if(debug_fast_baud)
  {
    // 9600 NMEA is the default baud rate for Adafruit MTK GPS's- some use 4800
    GPS.begin(9600);
    DSerial.println("faster baud");
    GPS.sendCommand(PMTK_SET_BAUD_57600);
    delay(500);
    GPS.begin(57600);
    delay(500);
    DSerial.println("faster baud done");
  } else {
    // 9600 NMEA is the default baud rate for Adafruit MTK GPS's- some use 4800
    GPS.begin(57600);
    DSerial.println("slower baud");
    GPS.sendCommand(PMTK_SET_BAUD_9600);
    delay(500);
    GPS.begin(9600);
    delay(500);
    DSerial.println("slower baud done");
  }
  
  // uncomment this line to turn on RMC (recommended minimum) and GGA (fix data) including altitude
  //GPS.sendCommand(PMTK_SET_NMEA_OUTPUT_RMCGGA);
  // uncomment this line to turn on only the "minimum recommended" data
  GPS.sendCommand(PMTK_SET_NMEA_OUTPUT_RMCONLY);
  // For parsing data, we don't suggest using anything but either RMC only or RMC+GGA since
  // the parser doesn't care about other sentences at this time
  
  // Set the update rate
  if(debug_fast_update) {
    GPS.sendCommand(PMTK_SET_NMEA_UPDATE_5HZ);   // 5 Hz update rate
    GPS.sendCommand(PMTK_API_SET_FIX_CTL_5HZ);
  } else {
    GPS.sendCommand(PMTK_SET_NMEA_UPDATE_1HZ);   // 1 Hz update rate
    GPS.sendCommand(PMTK_API_SET_FIX_CTL_1HZ);
  }
  
  
  // For the parsing code to work nicely and have time to sort thru the data, and
  // print it out we don't suggest using anything higher than 1 Hz

  // Turn off updates on antenna status
  GPS.sendCommand(PGCMD_NOANTENNA);

  // the nice thing about this code is you can have a timer0 interrupt go off
  // every 1 millisecond, and read data from the GPS for you. that makes the
  // loop code a heck of a lot easier!
  useInterrupt(true);

  delay(1000);
  // Ask for firmware version
  //GPS.sendCommand(PMTK_Q_RELEASE);
  
  
  DSerial.println("setupGPS() done");
}

void setupLCD()
{
  
  //HACK: new stuff from GFX library, should probably be in library
#if defined(ILI9340_RST_PIN)
  FastPin<ILI9340_RST_PIN>::setOutput();
  FastPin<ILI9340_RST_PIN>::hi();
  FastPin<ILI9340_RST_PIN>::lo();
  delay(1);
  FastPin<ILI9340_RST_PIN>::hi();
#endif

  tft.begin();
  //HACK: new stuff from GFX library, should probably be in library
  SPI.setClockDivider(SPI_CLOCK_DIV2);	// 8 MHz (full! speed!) [1 byte every 18 cycles]

  DSerial.println("init");

  uint16_t time = millis();
  tft.fillScreen(bgColor);
  time = millis() - time;
  DSerial.println(time, DEC);
  
  pinMode(light, OUTPUT);
  digitalWrite(light, HIGH);
  //analogWrite(light, 128);
}


void loop() {
  gpsLoop();
  tempReadLoop();
  
  //Tests
  //testUIBars();
  
  if(debug_demo_mode) {
    testUISpeed();
    testUIDateTime();
  }

  calculateUI();
  
  if(debug_demo_mode) {
    testUITemp(); //Must run after calculateUI()
  }
  
  updateUI();
  //delay(100);
}

void testUITemp()
{
  //115-275
  static int coolantTemp = 100;
  static int direction = 1;
  
  coolantTemp += direction;
  displayF.coolantTempValue = coolantTemp;
  sprintf(displayF.coolantTemp, "%3d", displayF.coolantTempValue);  
  sensorsUpdated.coolantValue = 1;
  
  
  //32-106
  static int inOutTemp = -19;
  
  inOutTemp += direction;
  displayF.outsideTempValue = inOutTemp;
  sprintf(displayF.outsideTemp, "%3d", displayF.outsideTempValue);  
  sensorsUpdated.outsideValue = 1;  

  displayF.insideTempValue = inOutTemp;
  sprintf(displayF.insideTemp, "%3d", displayF.insideTempValue);  
  sensorsUpdated.insideValue = 1;  
  
  if(inOutTemp >= 175 || inOutTemp <= -20){
    direction = -direction;
  }
}

void testUIBars()
{
  static int bartest = 0;
  static int direction = 1;
  drawUITopBar(bartest, COLOR_RED);
  
  bartest += direction;
  if(bartest >= 318 || bartest <= 0){
    direction = -direction;
  }
  
  static int smallbartest = 0;
  static int smalldirection = 1;
 
  //drawUILeftBar(smallbartest, COLOR_WHITE);
  //drawUIRightBar(smallbartest, COLOR_WHITE);
  
  smallbartest += smalldirection;
  if(smallbartest >= 68 || smallbartest <= 0){
    smalldirection = -smalldirection;
  }
  
  
}

void testUISpeed()
{
  static int speedtest = 0;
  static int direction = 1;
  
  sensorValues.speedMPH = speedtest;
  sensorsUpdated.speedKnots = 1;
  speedtest += direction;
  if(speedtest >= 110 || speedtest <= 0){
    direction = -direction;
  }
  
  //delay(250);
}

void testUIDateTime()
{
  static int dateMonth = 0;
  static int dateDay   = 0;
  static int timeHour  = 0;
  static int timeMin   = 0;
  
  
  dateMonth++;
  dateDay++;
  timeHour++;
  timeMin++;
  
  if(dateMonth > 12) dateMonth = 1;
  if(dateDay   > 31) dateDay = 1;
  if(timeHour  > 12) timeHour = 1;
  if(timeMin   > 59) timeMin = 0;
  
  
  
  sensorValues.month = dateMonth;
  sensorValues.day   = dateDay;
  sensorValues.hour  = timeHour;
  sensorValues.min   = timeMin;
  
  sensorsUpdated.month = 1;
  sensorsUpdated.day = 1;
  sensorsUpdated.hour = 1;
  sensorsUpdated.min = 1;
  
}

void calculateUI()
{
  int celsius = 0;
  
  //The plus 4 is to minimize rounding errors (half of 9 = 4.5)
  if(sensorsUpdated.coolantValue != 0){
    displayF.coolantTempValue = ((69529.0 - 9334.0 * log(sensorValues.coolantValue)) / 100.0);
    sprintf(displayF.coolantTemp, "%3d", displayF.coolantTempValue);  
    celsius = ((displayF.coolantTempValue - 32)*5+4)/9;
    sprintf(displayC.coolantTemp, "%3d", celsius);  
  }
  if(sensorsUpdated.outsideValue != 0){
    displayF.outsideTempValue = ((90000.0 - (100.0 * sensorValues.outsideValue)) / 619.0);
    sprintf(displayF.outsideTemp, "%3d", displayF.outsideTempValue); 
    celsius = ((displayF.outsideTempValue - 32)*5+4)/9; 
    sprintf(displayC.outsideTemp, "%3d", celsius);  
  }
  if(sensorsUpdated.insideValue != 0){
    displayF.insideTempValue = ((90000.0 - (100.0 * sensorValues.insideValue)) / 619.0);
    sprintf(displayF.insideTemp, "%3d", displayF.insideTempValue);  
    celsius = ((displayF.insideTempValue - 32)*5+4)/9;
    sprintf(displayC.insideTemp, "%3d", celsius);
  }
  
  if (sensorsUpdated.speedKnots != 0) {
    
    //Serial.print("Speed (knots): "); Serial.println(sensorValues.speed);
    //Serial.print("Speed   (mph): "); Serial.println(sensorValues.speed * 1.15078);
    //Serial.print("Speed   (kph): "); Serial.println(sensorValues.speed * 1.852);
    
    //TODO: support 100+ numbers
    if(sensorValues.speedMPH > 99) sensorValues.speedMPH = 99;
    if(sensorValues.speedKPH > 99) sensorValues.speedKPH = 99;
    
    //Hide low values
    if(sensorValues.speedMPH <= 2) sensorValues.speedMPH = 0;
    if(sensorValues.speedKPH <= 3) sensorValues.speedKPH = 0;
    
    sprintf(displayF.speed, "%2d", sensorValues.speedMPH); 
    sprintf(displayC.speed, "%2d", sensorValues.speedKPH); 
  }
  if (sensorsUpdated.min != 0) {  
    sprintf(displayF.time, "%2d:%02d", sensorValues.hour, sensorValues.min);  
    sprintf(displayC.time, "%2d:%02d", sensorValues.hour, sensorValues.min);  
  }
  if (sensorsUpdated.day != 0) {
    sprintf(displayF.date, "%2d/%2d", sensorValues.month, sensorValues.day);  
    sprintf(displayC.date, "%2d/%2d", sensorValues.day, sensorValues.month);  
  }
}

void tempReadLoop()
{
  int sensorAnalogValue = analogRead(tempCoolantPin);
  if (sensorAnalogValue != sensorValues.coolantValue &&
      (sensorAnalogValue != sensorValues.coolantValue + 1) &&
      (sensorAnalogValue != sensorValues.coolantValue - 1))
  {
    sensorValues.coolantValue = sensorAnalogValue;
    sensorsUpdated.coolantValue = 1;
  }
  sensorAnalogValue = analogRead(tempOutsidePin);
  if (sensorAnalogValue != sensorValues.outsideValue &&
      (sensorAnalogValue != sensorValues.outsideValue + 1) &&
      (sensorAnalogValue != sensorValues.outsideValue - 1))
  {
    sensorValues.outsideValue = sensorAnalogValue;
    sensorsUpdated.outsideValue = 1;
  }
  sensorAnalogValue = analogRead(tempInsidePin);
  if (sensorAnalogValue != sensorValues.insideValue &&
      (sensorAnalogValue != sensorValues.insideValue + 1) &&
      (sensorAnalogValue != sensorValues.insideValue - 1))
  {
    sensorValues.insideValue = sensorAnalogValue;
    sensorsUpdated.insideValue = 1;
  }
  
}

#pragma mark - GPS Callbacks


// Interrupt is called once a millisecond, looks for any new GPS data, and stores it
SIGNAL(TIMER0_COMPA_vect) {
  char c = GPS.read();
  // if you want to debug, this is a good time to do it!
#ifdef UDR0
  if (GPSECHO)
    if (c) UDR0 = c;  
    // writing direct to UDR0 is much much faster than Serial.print 
    // but only one character can be written at a time. 
#endif
}

void useInterrupt(boolean v) {
  if (v) {
    // Timer0 is already used for millis() - we'll just interrupt somewhere
    // in the middle and call the "Compare A" function above
    OCR0A = 0xAF;
    TIMSK0 |= _BV(OCIE0A);
    usingInterrupt = true;
  } else {
    // do not call the interrupt function COMPA anymore
    TIMSK0 &= ~_BV(OCIE0A);
    usingInterrupt = false;
  }
}

uint32_t timer = millis();
void gpsLoop()
{
  char *lastNMEA;
  // in case you are not using the interrupt above, you'll
  // need to 'hand query' the GPS, not suggested :(
  if (! usingInterrupt) {
    // read data from the GPS in the 'main loop'
    char c = GPS.read();
    // if you want to debug, this is a good time to do it!
    if (GPSECHO)
      if (c) DSerial.print(c);
  }
  
  // if a sentence is received, we can check the checksum, parse it...
  if (GPS.newNMEAreceived()) {
    // a tricky thing here is if we print the NMEA sentence, or data
    // we end up not listening and catching other sentences! 
    // so be very wary if using OUTPUT_ALLDATA and trytng to print out data
    //Serial.println(GPS.lastNMEA());   // this also sets the newNMEAreceived() flag to false
  
    lastNMEA = GPS.lastNMEA();
    if (!GPS.parse(lastNMEA))   // this also sets the newNMEAreceived() flag to false
    {
      DSerial.println("GPS parse failed");
      return;  // we can fail to parse a sentence in which case we should just wait for another
    }
  }

  // if millis() or timer wraps around, we'll just reset it
  if (timer > millis())  timer = millis();

  // approximately every 0.5 seconds or so, print out the current stats
  if (millis() - timer > 200) {
    DSerial.print("has fix = ");
    DSerial.println(GPS.fix);
    timer = millis(); // reset the timer
    /*
    Serial.print("\nTime: ");
    Serial.print(GPS.hour, DEC); Serial.print(':');
    Serial.print(GPS.minute, DEC); Serial.print(':');
    Serial.print(GPS.seconds, DEC); Serial.print('.');
    Serial.println(GPS.milliseconds);
    Serial.print("Date: ");
    Serial.print(GPS.day, DEC); Serial.print('/');
    Serial.print(GPS.month, DEC); Serial.print("/20");
    Serial.println(GPS.year, DEC);
    Serial.print("Fix: "); Serial.print((int)GPS.fix);
    Serial.print(" quality: "); Serial.println((int)GPS.fixquality); 
    if (GPS.fix) {
      Serial.print("Location: ");
      Serial.print(GPS.latitude, 4); Serial.print(GPS.lat);
      Serial.print(", "); 
      Serial.print(GPS.longitude, 4); Serial.println(GPS.lon);
      
      Serial.print("Speed (knots): "); Serial.println(GPS.speed);
      Serial.print("Angle: "); Serial.println(GPS.angle);
      Serial.print("Altitude: "); Serial.println(GPS.altitude);
      Serial.print("Satellites: "); Serial.println((int)GPS.satellites);
    }
    /**/
    
    if (sensorValues.min != GPS.minute)
    {
      //TODO: this is UTC time        
      setTime(GPS.hour, GPS.minute, 0, GPS.day, GPS.month, GPS.year);
      time_t rawTime = now();
      
      /*
      DSerial.println("================");
      DSerial.print(GPS.hour);
      DSerial.print(":");
      DSerial.println(GPS.minute);
      DSerial.print(GPS.month);
      DSerial.print("/");
      DSerial.print(GPS.day);
      DSerial.print("/");
      DSerial.println(2000+GPS.year);
      DSerial.println("==--------------");
      */
      
      
      DSerial.println("====");
      DSerial.print(hour());
      DSerial.print(":");
      DSerial.println(minute());
      DSerial.print(hour(rawTime));
      DSerial.print(":");
      DSerial.println(minute(rawTime));
      
      int GSTOffset = -8 + offsetDST;
      //adjustTime(-7*60*60); //PDT
      //adjustTime(-8*60*60); //PST
      adjustTime(GSTOffset*60*60);
      rawTime = now();
      
      DSerial.println("----");
      DSerial.print(hour());
      DSerial.print(":");
      DSerial.println(minute());
      DSerial.print(hour(rawTime));
      DSerial.print(":");
      DSerial.println(minute(rawTime));
        
      
      if (sensorValues.month != month(rawTime) || sensorValues.day != day(rawTime))
      {
        sensorValues.month = month(rawTime);
        sensorValues.day   = day(rawTime);
        
        sensorsUpdated.month = 1;
        sensorsUpdated.day = 1;
      }
  
      if (sensorValues.hour != hour(rawTime) || sensorValues.min != minute(rawTime))
      {
        sensorValues.hour  = hour(rawTime);
        sensorValues.min   = minute(rawTime);
        if (sensorValues.hour > 12) sensorValues.hour -= 12;
        
        sensorsUpdated.hour = 1;
        sensorsUpdated.min = 1;
      }
    
    }
    //TODO: Just assume this is always updating?
    //TODO: Should at least calculate mph values to compare
    sensorValues.fix   = GPS.fix;
    if (GPS.fix){
      
      if (sensorValues.speedKnots != GPS.speed)
      {
        sensorValues.speedKnots = GPS.speed;
        sensorValues.speedMPH = (int)((sensorValues.speedKnots * 1.15078) + 0.5); //mph round up 
        sensorValues.speedKPH = (int)((sensorValues.speedKnots * 1.852) + 0.5);  //kph round up 
 
        sensorsUpdated.speedKnots = 1;
      }
    }
  }
}

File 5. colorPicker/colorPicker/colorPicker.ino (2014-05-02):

/***************************************************
  This is an example sketch for the Adafruit 1.8" SPI display.
  This library works with the Adafruit 1.8" TFT Breakout w/SD card
  ----> http://www.adafruit.com/products/358
  as well as Adafruit raw 1.8" TFT display
  ----> http://www.adafruit.com/products/618
 
  Check out the links above for our tutorials and wiring diagrams
  These displays use SPI to communicate, 4 or 5 pins are required to
  interface (RST is optional)
  Adafruit invests time and resources providing this open source code,
  please support Adafruit and open-source hardware by purchasing
  products from Adafruit!

  Written by Limor Fried/Ladyada for Adafruit Industries.
  MIT license, all text above must be included in any redistribution
 ****************************************************/

// For the breakout, you can use any (2 or) 3 pins
//#define sclk 13
//#define mosi 11
#define cs   10
#define dc   9
#define rst  8  // you can also connect this to the Arduino reset
#define light 5
//Use these pins for the shield!
//#define cs   10
//#define dc   8
//#define rst  0  // you can also connect this to the Arduino reset

#include <Adafruit_GFX.h>    // Core graphics library
#include <Adafruit_ST7735.h> // Hardware-specific library
#include <SPI.h>

#if defined(__SAM3X8E__)
    #undef __FlashStringHelper::F(string_literal)
    #define F(string_literal) string_literal
#endif

// Option 1: use any pins but a little slower
//Adafruit_ST7735 tft = Adafruit_ST7735(cs, dc, mosi, sclk, rst);

// Option 2: must use the hardware SPI pins
// (for UNO thats sclk = 13 and sid = 11) and pin 10 must be
// an output. This is much faster - also required if you want
// to use the microSD card (see the image drawing example)
Adafruit_ST7735 tft = Adafruit_ST7735(cs, dc, rst);
float p = 3.1415926;


int sensorPin1 = A0;
int sensorPin2 = A1;
int sensorPin3 = A2;

int sensorValue1 = 0;
int sensorValue2 = 0;
int sensorValue3 = 0;


void setup(void) {
  Serial.begin(9600);
  Serial.print("hello!");

  // Our supplier changed the 1.8" display slightly after Jan 10, 2012
  // so that the alignment of the TFT had to be shifted by a few pixels
  // this just means the init code is slightly different. Check the
  // color of the tab to see which init code to try. If the display is
  // cut off or has extra 'random' pixels on the top & left, try the
  // other option!
  // If you are seeing red and green color inversion, use Black Tab

  // If your TFT's plastic wrap has a Black Tab, use the following:
  tft.initR(INITR_BLACKTAB);   // initialize a ST7735S chip, black tab
  // If your TFT's plastic wrap has a Red Tab, use the following:
  //tft.initR(INITR_REDTAB);   // initialize a ST7735R chip, red tab
  // If your TFT's plastic wrap has a Green Tab, use the following:
  //tft.initR(INITR_GREENTAB); // initialize a ST7735R chip, green tab

  Serial.println("init");

  uint16_t time = millis();
  tft.fillScreen(ST7735_BLACK);
  time = millis() - time;

  Serial.println(time, DEC);
  delay(500);

  pinMode(light, OUTPUT);
  digitalWrite(light, HIGH);

  setupText(ST7735_WHITE);
    
  tft.setRotation(1);
  
  Serial.println("done");
  delay(1000);
}

void loop() {
  checkForUpdatedTemp();
  delay(100);
}

void updateUI()
{
  tft.setTextColor(tft.Color565(sensorValue1, sensorValue2, sensorValue3), ST7735_BLACK);
  
  drawText("R = ",  0, 10);
  tft.print(sensorValue1);
  tft.print("     "); //for values that get shorter
  
  drawText("G = ",  0, 30);
  tft.print(sensorValue2);
  tft.print("     "); //for values that get shorter
  
  drawText("B = ",  0, 50);
  tft.print(sensorValue3);
  tft.print("     "); //for values that get shorter
}

void setupText(uint16_t color)
{
  tft.setCursor(0, 0);
  tft.setTextColor(color, ST7735_BLACK);
  tft.setTextWrap(false);
}

void drawText(char *text, uint8_t x, uint8_t y) {
  tft.setCursor(0, y);
  tft.print(text);
}

void drawMoreText(char *text)
{
  tft.print(text);
}

void checkForUpdatedTemp()
{
  int updated = 0;
  
  int newSensorValue1 = analogRead(sensorPin1);
  int newSensorValue2 = analogRead(sensorPin2);
  int newSensorValue3 = analogRead(sensorPin3);
  
  newSensorValue1 = map(newSensorValue1, 0, 1023, 0, 255);
  newSensorValue2 = map(newSensorValue2, 0, 1023, 0, 255);
  newSensorValue3 = map(newSensorValue3, 0, 1023, 0, 255);
  
  if (newSensorValue1 != sensorValue1) updated = 1;
  if (newSensorValue2 != sensorValue2) updated = 1;
  if (newSensorValue3 != sensorValue3) updated = 1;
  
  if (updated)
  {
    sensorValue1 = newSensorValue1;
    sensorValue2 = newSensorValue2;
    sensorValue3 = newSensorValue3;
    
    Serial.print(sensorValue1);
    Serial.print("\t");
    Serial.print(sensorValue2);
    Serial.print("\t");
    Serial.print(sensorValue3);
    Serial.println();
    
    updateUI();
  }
}


void testlines(uint16_t color) {
  tft.fillScreen(ST7735_BLACK);
  for (int16_t x=0; x < tft.width(); x+=6) {
    tft.drawLine(0, 0, x, tft.height()-1, color);
  }
  for (int16_t y=0; y < tft.height(); y+=6) {
    tft.drawLine(0, 0, tft.width()-1, y, color);
  }

  tft.fillScreen(ST7735_BLACK);
  for (int16_t x=0; x < tft.width(); x+=6) {
    tft.drawLine(tft.width()-1, 0, x, tft.height()-1, color);
  }
  for (int16_t y=0; y < tft.height(); y+=6) {
    tft.drawLine(tft.width()-1, 0, 0, y, color);
  }

  tft.fillScreen(ST7735_BLACK);
  for (int16_t x=0; x < tft.width(); x+=6) {
    tft.drawLine(0, tft.height()-1, x, 0, color);
  }
  for (int16_t y=0; y < tft.height(); y+=6) {
    tft.drawLine(0, tft.height()-1, tft.width()-1, y, color);
  }

  tft.fillScreen(ST7735_BLACK);
  for (int16_t x=0; x < tft.width(); x+=6) {
    tft.drawLine(tft.width()-1, tft.height()-1, x, 0, color);
  }
  for (int16_t y=0; y < tft.height(); y+=6) {
    tft.drawLine(tft.width()-1, tft.height()-1, 0, y, color);
  }
}

void testdrawtext(char *text, uint16_t color) {
  tft.setCursor(0, 0);
  tft.setTextColor(color);
  tft.setTextWrap(true);
  tft.print(text);
}

void testfastlines(uint16_t color1, uint16_t color2) {
  tft.fillScreen(ST7735_BLACK);
  for (int16_t y=0; y < tft.height(); y+=5) {
    tft.drawFastHLine(0, y, tft.width(), color1);
  }
  for (int16_t x=0; x < tft.width(); x+=5) {
    tft.drawFastVLine(x, 0, tft.height(), color2);
  }
}

void testdrawrects(uint16_t color) {
  tft.fillScreen(ST7735_BLACK);
  for (int16_t x=0; x < tft.width(); x+=6) {
    tft.drawRect(tft.width()/2 -x/2, tft.height()/2 -x/2 , x, x, color);
  }
}

void testfillrects(uint16_t color1, uint16_t color2) {
  tft.fillScreen(ST7735_BLACK);
  for (int16_t x=tft.width()-1; x > 6; x-=6) {
    tft.fillRect(tft.width()/2 -x/2, tft.height()/2 -x/2 , x, x, color1);
    tft.drawRect(tft.width()/2 -x/2, tft.height()/2 -x/2 , x, x, color2);
  }
}
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

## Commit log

2014-04-18 add lcd printing of analog data
2014-04-18 Add string processing for output
    - convert numbers to strings for C and F
    - only update the strings and the screen when numbers are changed
    - turn off interrupts for now
2014-04-18 Update UI drawing
    - Add text to the initial UI (too long)
    - Test º degrees symbol text support
    - Test drawBitmap function
    - Fix some ui location issues
    [johnsCarProject.ino]
2014-04-19 Update drawing of 8 and 9
    - Add 8 and 9 drawing to pde sample UI
    - Add 8 and 9 drawing to ino LCD drawing
2014-04-19 Fix rotation bug
    - Rotation is now set to 1 (90º)
    - Revert changes to drawBitmap because Johns library doesn't have the changes yet.
    [colorPicker.ino, johnsCarProject.ino, lcdPrintTest.ino]
2014-04-19 Fix colorPicker analog mapping
    - color565 function wanted 0-255 as values
    [colorPicker.ino]
2014-04-19 Turn on interrupt for GPS data
2014-04-19 Prepare for large speed type
    - Add rest of the 0-9 numbers
    - Print the numbers (commented out for now)
    - John needs my version of the Adafruit-GFX library before he can test it
2014-05-02 Fix bug where speed wasn't working
    - Fix speed bug (wasn't casting to an int)
    - Add rest of the numbers other than 8,9
    - Add blank drawing for zeroing out 10s place when going from 10->9
    - Fix zero bitmap error
    - Add lcd backlight turn on in all lcd sketches (pin 5 high)
    - Add initial schematic from John (pdf)
    [colorPicker.ino, graphicstest_highspeed.ino, johnsCarProject.ino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]
2014-05-02 Speed up updates
    - Set to 5hz update speed
    - Updates every 500 ms
    - Remove adafruit logo
    - Remove º symbol
    - Remove Serial prints in gps updates
2014-05-05 Fix bitmaps for numbers 5 and 4
    [johnsCarProject.ino]
2014-05-05 Reorganize and optimize
    - Move calculate and updateUI to main loop
    - Change around how speed is calculated and updated
    - Remove antenna output
2014-05-08 Add Johns temperature calculation for inside temp sensor
    - From John: TemperatureF = (((90000 - (100 * A/D)) / 619)
    - That is ºF with the GM sensor in a 5v system with a 15k pull up.
2014-05-09 Add calculation for coolant sensor
    - Fix some issues with unsigned ints
    - Added calculated temp to the displayF/C struct
    [johnsCarProject.ino]
2014-05-09 Add Inside bar update
    - Add drawUIInsideTemp() function, add to updateUI()
    - Update drawUIRightBar() function for new drawing
    - Fix testUITemp() function, must comment out calculateUI() to run
    [johnsCarProject.ino]
2014-08-29 Started work on large screen convert
    - Add time library
    - Commit before il 2.2 screen test
2014-08-29 Update for staging UI
    - Added bounding boxes for UI update
    - Updated some code in preparation for arduino 1.5, should work with 1.1
2014-09-05 Fix coolant bar text
    - Move coolant bar text to the right side when under 165
    - Change temp text to blue when negative (until dash symbol from John)
    - Move Coolant text down two pixels from 5 to 7
    [symbols.ino, updateUI.ino]
2014-09-10 Add demo mode
    - Add #define for DEMO_MODE
    - Fix issue #7 Coolant symbol draws white on white bar
    [johnsCarProject.ino, symbols.ino, updateUI.ino]
2014-09-26 Update segments on Speed Font
    - Add more segments to speed font to fix the display issues
    - Remove some old unused functions for old seven segment drawing
    [speedFont.ino]
2014-09-26 Redo segments to tweak font style
    - Add extra segment
    - Tweak size of segments to stylize speed font
    - Add speed font locations and sizes
    [SPEEDO_POSITIONS.xlsx]
2014-11-15 Update to use PDQ GFX library
    - Change includes
    - Change declaration of tft
    - Add extra lines to setup for library to not horribly fail
    [johnsCarProject.ino]
2014-12-06 Fix Daylight saving offset
    - Added one line for PDT and one for PST
    - Will add manual configuration later
    [johnsCarProject.ino]
2014-12-06 Smooth out temperature changes
    - Only update temp if analog value has changed by at least 2
2014-12-06 Add schematics for the boards
    - v2 is the current red board
    - v3 is at the board house and already bypassed, fixed display rotation
    - v4 has fixes from v2 and v3
    [2014-11-21_2.2_lcd_13.brd, 2014-11-21_2.2_lcd_13.sch, 2014-12-3_2.2_lcd_26.brd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]
2015-02-06 Add debug flags
    - flag for demo mode
    - flag for fast updates
    - flag for fast baud
    - flag for show gps fix
    [johnsCarProject.ino]
2015-02-06 Add buttons and save to eeprom
    - left button for toggle dst. 0/+1
    - right button for toggle mph. imperial/metric
    - hide low speedo values

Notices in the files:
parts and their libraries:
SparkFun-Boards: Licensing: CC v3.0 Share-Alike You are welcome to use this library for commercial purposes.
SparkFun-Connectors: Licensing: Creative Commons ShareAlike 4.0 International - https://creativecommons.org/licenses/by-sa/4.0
